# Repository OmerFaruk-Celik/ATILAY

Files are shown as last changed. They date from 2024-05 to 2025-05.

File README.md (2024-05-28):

# ATILAY: Bilgi Paylaşımıyla Güçleniyoruz!

👋 Teknofest İnsansız Su Altı Otonom yarışmasında ATILAY takımı olarak yola çıkarken hedefimiz sadece yarışmayı kazanmak değildi. Aynı zamanda yazılım alanındaki bilgi birikimimizi siz yeni başlayanlarla paylaşarak Türkiye'deki kaynak sorununa çözüm bulmaktı. 🇹🇷

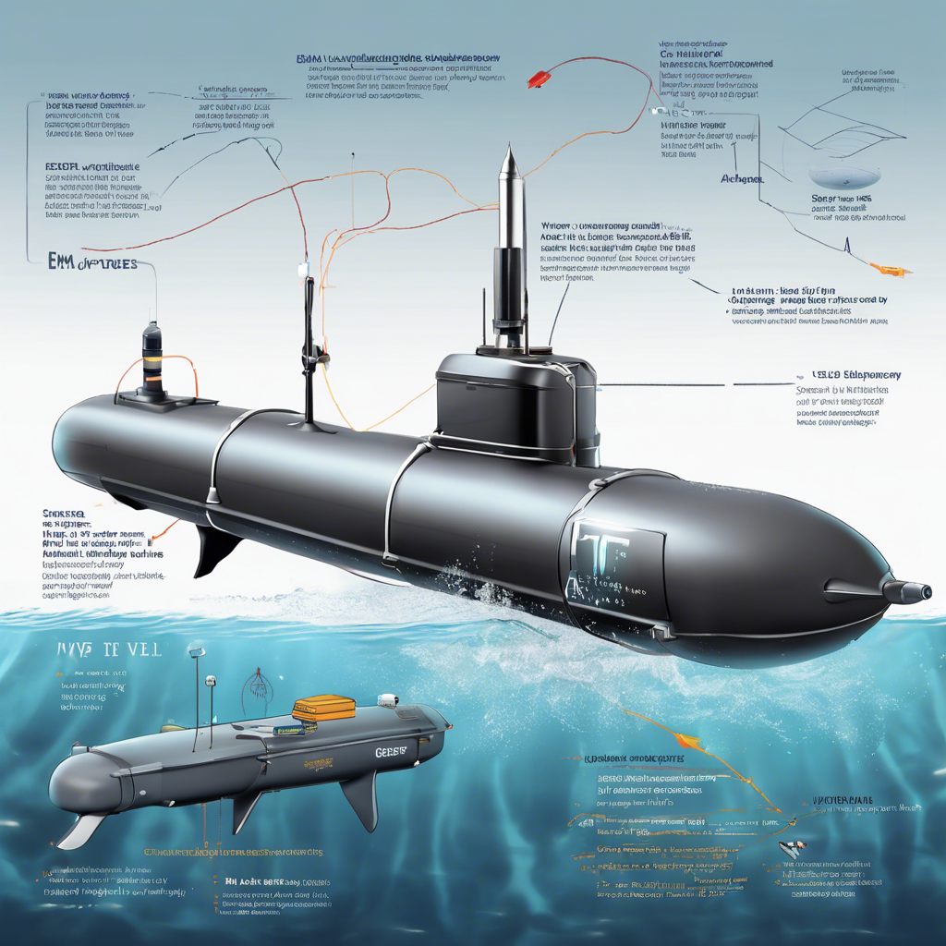
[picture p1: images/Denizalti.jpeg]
Denizaltı


Bildiğiniz gibi, özellikle Türkçe kaynak bulmak oldukça zor olabiliyor. ATILAY olarak biz de bu zorluğun farkındayız. İşte bu yüzden edindiğimiz tüm bilgi ve tecrübeleri sizlerle paylaşarak bu sorunu aşmanıza yardımcı olmak istiyoruz.

İnancımız, gerçek gücün bilgiyi paylaştıkça artacağı yönünde! Günümüzün yapay zeka çağında, iş birliği ve bilgiye erişim her zamankinden daha önemli. Açık kaynak kod felsefesini benimseyerek "Windowsça değil, Linuxça" davranmayı ve hep birlikte gelişmeyi hedefliyoruz. 🐧

GitHub hesabımızda sizlerle paylaşacağımız kaynaklar; tecrübelerimizden faydalanmanız, sorular sormanız ve hep birlikte daha güçlü bir yazılım topluluğu oluşturmanız için bir fırsat sunuyor! 💻

Unutmayın, bilgi paylaştıkça çoğalır! ✨

# ATILAY: 2024 TEKNOFEST İnsansız Su Altı Sistemleri Yarışması

## 🏆  ATILAY Takımı

**Bu proje, 2024 TEKNOFEST İnsansız Su Altı Sistemleri Yarışması'nda "İleri Kategori"de yarışmak için oluşturulan ATILAY Takımı tarafından gerçekleştirilmektedir.**

**Takımımız:**

* **[Takım Üyelerinin Adları ve Rolleri]** 
* **Danışman:** [Danışmanın Adı ve Ünvanı]

**Başvuru ID:** 1295858

## 🚀  Proje Hedefi: Sualtı Keşif ve Operasyonlarda Yenilikçi Çözümler

**ATILAY** olarak, ülkemizin deniz kaynaklarını daha iyi keşfetmek, denizaltı araştırmalarını geliştirmek ve acil durumlarda hızlı müdahaleyi sağlamak için **insansız su altı sistemleri teknolojisine** odaklanmış, yenilikçi bir proje geliştirdik. 

**Projemizin temel amacı, sualtı araçlarına, GPS sinyallerinin ulaşamadığı ortamlarda da güvenli ve etkili bir konumlandırma yeteneği kazandırmaktır.** Bu sayede, sualtı keşifleri ve operasyonları daha verimli, güvenli ve maliyet etkin hale gelecektir.

## ⚙️  ATILAY: Sualtı Araçları için Arttırılabilir Menzilli Konumlandırma Sistemi (AMKS)

**AMKS**, sualtında ses dalgalarını kullanarak, ikili sayılarla kodlanmış zaman bilgisi ile aracın konumunu belirleyen yenilikçi bir sistemdir.

**AMKS'nin temel özellikleri:**

* **Uzun Menzil:**  Sinyal güçlendirici sayesinde, AMKS geleneksel sistemlere göre daha uzun mesafelerde konum belirleme olanağı sağlar.
* **Taşınabilirlik:**  İstasyonlar, aracın boyutuna göre ölçeklendirilebilir ve istenilen konuma yerleştirilebilir.
* **Maliyet Etkinliği:**  AMKS, LBL, SBL ve USBL sistemlerine kıyasla daha düşük maliyetlidir.
* **Güvenlik:**  Aracın konumunu belirlemek için birden fazla istasyon ve iki yönlü ölçüm gerektirmez.
* **Gizlilik:**  AMKS, pasif sonar prensibiyle çalıştığı için aracın konumunu aktif olarak ifşa etmez.

## 🤖  Yazılım ve Algoritmalar

**AMKS'nin çekirdeğini, güçlü bir yazılım ve algoritma seti oluşturmaktadır:**

* **Raspberry Pi 4:**  Aracın beyni olarak görev yapar, sensör verilerini işler, algoritmaları çalıştırır ve kontrol sinyalleri üretir.
* **Google Coral Devletme Kartı:**  Görüntü işleme ve derin öğrenme uygulamaları için kullanılır.  
* **Python:** Ana programlama dili olarak seçilmiştir, zengin kütüphaneleri ve kolay kullanım imkanı sunar. 
* **OpenCV:** Görüntü işleme ve analiz için kullanılır (örneğin, hedef algılama, renk tespiti).
* **NumPy:** Nümerik hesaplamalar için kullanılır (örneğin, matris işlemleri).
* **Pandas:** Veri analizi ve manipülasyonu için kullanılır (örneğin, sensör verilerini işlemek).
* **Scikit-learn:** Makine öğrenmesi algoritmaları için kullanılır (örneğin, anomalileri tespit etmek).
* **Matplotlib:** Veri görselleştirme için kullanılır (örneğin, model performansını analiz etmek).

**Kullandığımız algoritmalar şunlardır:**

* **Arama ve Tarama Algoritması:** Araç, havuzun haritasını çıkararak hedefleri belirler ve tekrar taramaktan kaçınır.
* **Renk Tespiti ve Kapıdan Geçiş Algoritması:**  Aracın belirli renkleri tespit ederek, kapıdan geçmesini sağlar. 
* **Su Altı Kablo Takibi ve Anomali Tespiti Algoritması:**  Aracın su altı kablosunu takip etmesini ve üzerindeki anomalileri tespit etmesini sağlar.
* **Hedefe Torpido Fırlatma Algoritması:** Aracın hedefleri tespit etmesini ve torpidoları fırlatmasını sağlar.

## 📡  Sensörler

**AMKS'nin donanımını oluşturan sensörler:**

* **LIDAR-Lite v3HP:**  Yüksek hassasiyetli optik mesafe ölçüm sensörü (uzak mesafe ölçümü için).
* **TF03 (ToF) Lazer Mesafe Sensörü:**  Toz geçirmez, suya dayanıklı, 180m'ye kadar ölçüm yapabilen lazer sensörü (yakın mesafe ölçümü için).
* **Gravity BMX160+BMP388 10 DOF Sensör:**  İvmeölçer, jiroskop ve manyetometre  (aracın yönünü ve pozisyonunu belirlemek için).
* **Derinlik Basınç Sensörü:**  Aracın derinliğini ölçmek için kullanılır.
* **Ultrasonik Sensör:**  Aracın çevresindeki engelleri tespit etmek için kullanılır (yakın mesafe).
* **ELP 100 Derece Bozulma Yok HD Kamera Modülü:**  Sualtı görüntüleme için kullanılır (hedef tespiti, çevre analizi).
* **Sızıntı Sensörü:**  Su geçirmez haznede oluşabilecek sızıntıları tespit etmek için kullanılır.

## 🔌  Güç Yönetimi

**AMKS, enerji tasarrufu sağlayan bir güç yönetim sistemi kullanmaktadır:**

* **Markalonya 5000mAh 3.7 V 26650 Li-lon şarj edilebilir pil:**  Aracın enerji kaynağı.
* **3S 12.6V 4A Li-ion & Lipo Pil Şarj Devresi:**  Pilleri şarj etmek için kullanılır.
* **Elektronik Hız Sürücüsü (ESC):**  Motorların hızını ve yönünü kontrol eder.

## 🗺️  Proje Geliştirme Aşamaları

* **Sistem Tasarımı:**  AMKS'nin yapısal tasarımı, sensör seçimi, güç yönetimi, iletişim protokolleri gibi konuları kapsamaktadır.
* **Mekanik Tasarım:**  Aracın gövdesi, pervaneler, iticiler, su geçirmez hazne ve diğer mekanik parçalarının tasarımı ve üretimi.
* **Elektronik Tasarım:**  AMKS'nin elektronik bileşenlerinin seçimi, devre tasarımının yapılması ve prototipin oluşturulması.
* **Algoritma ve Yazılım Tasarımı:**  AMKS'nin otonom çalışmasını sağlayan algoritmaların geliştirilmesi, yazılım kodunun yazılması ve simülasyonlar.
* **Test ve Entegrasyon:**  Sistemin, laboratuvar ve havuz testlerinde denetlenmesi ve entegre edilmesi.

##  📸  Proje Görselleri

#Araç Tasarımı
AMKS Sistem Şeması
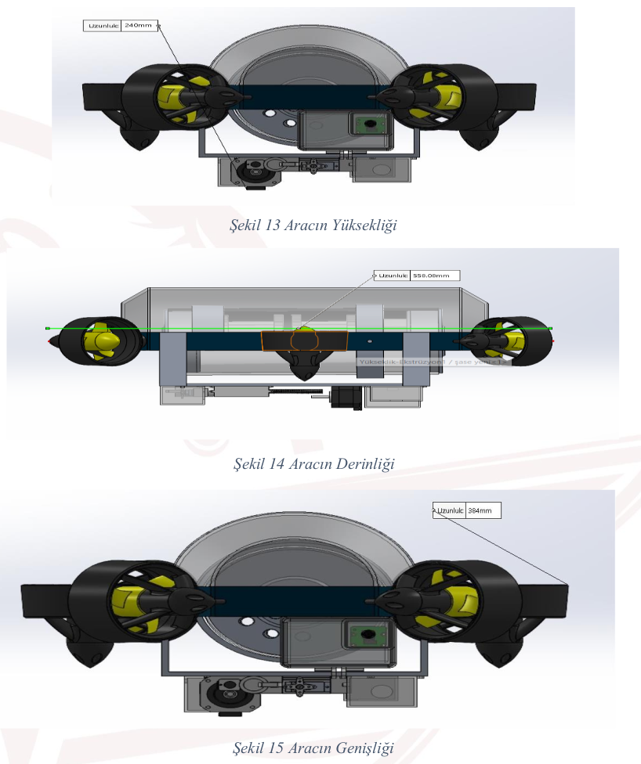
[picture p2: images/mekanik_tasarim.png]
Aracın Mekanik Tasarımı

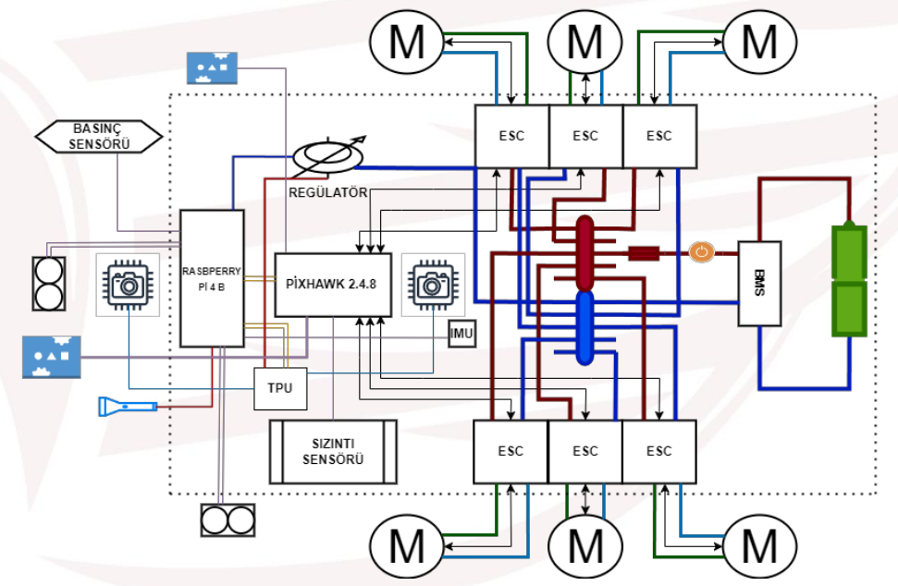
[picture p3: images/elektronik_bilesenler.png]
Elektronik Bileşenler


#Algoritmalar
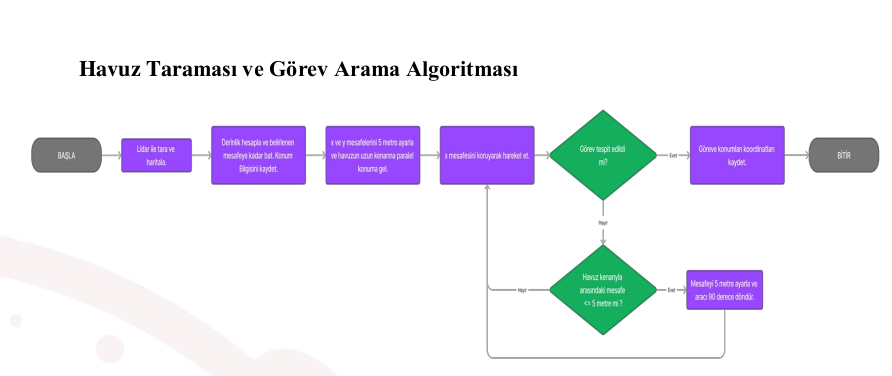
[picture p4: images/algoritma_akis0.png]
Algoritma Akış Diyagramı 1

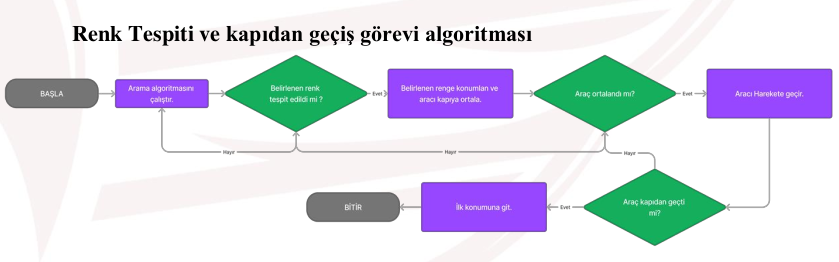
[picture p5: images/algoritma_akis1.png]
Algoritma Akış Diyagramı 2

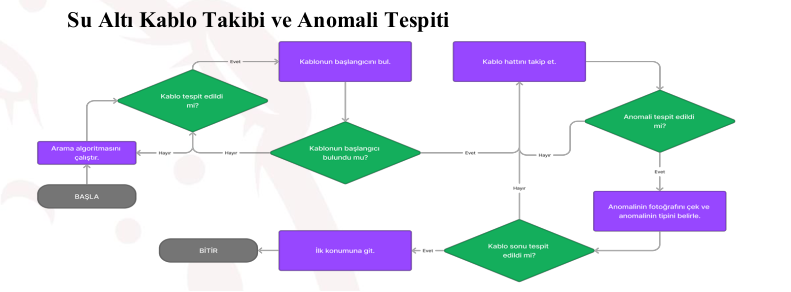
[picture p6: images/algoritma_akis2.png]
Algoritma Akış Diyagramı 3

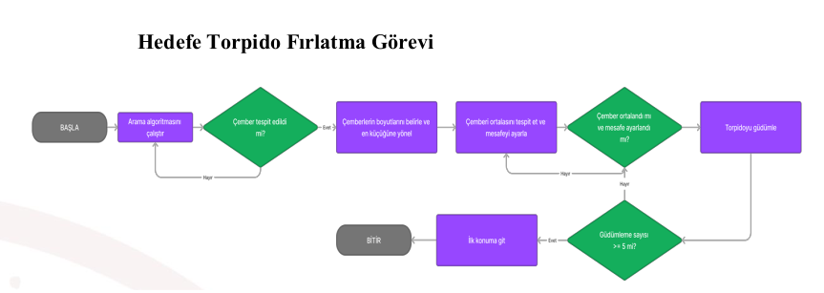
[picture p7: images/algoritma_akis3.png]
Algoritma Akış Diyagramı 4


#Didörtgen Tespiti
Dikdörgen Tespiti

#Simülasyonlar
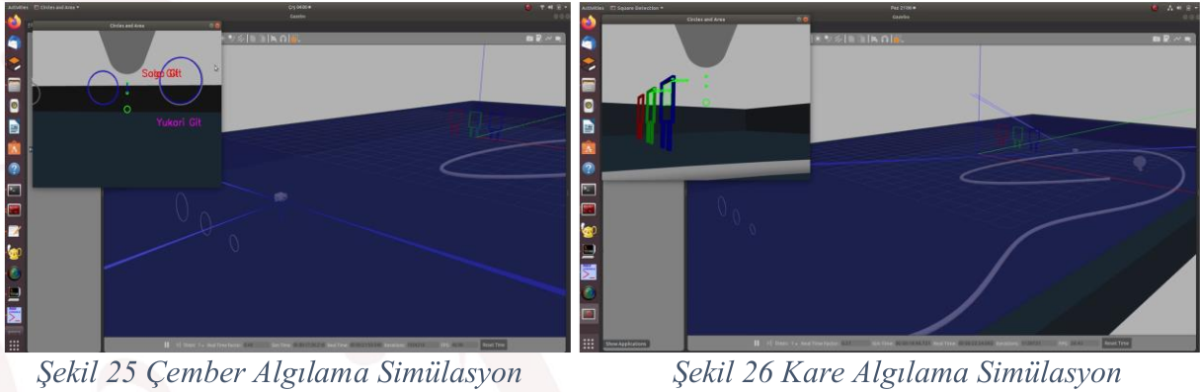
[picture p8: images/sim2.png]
Simülasyon Görüntüsü 1

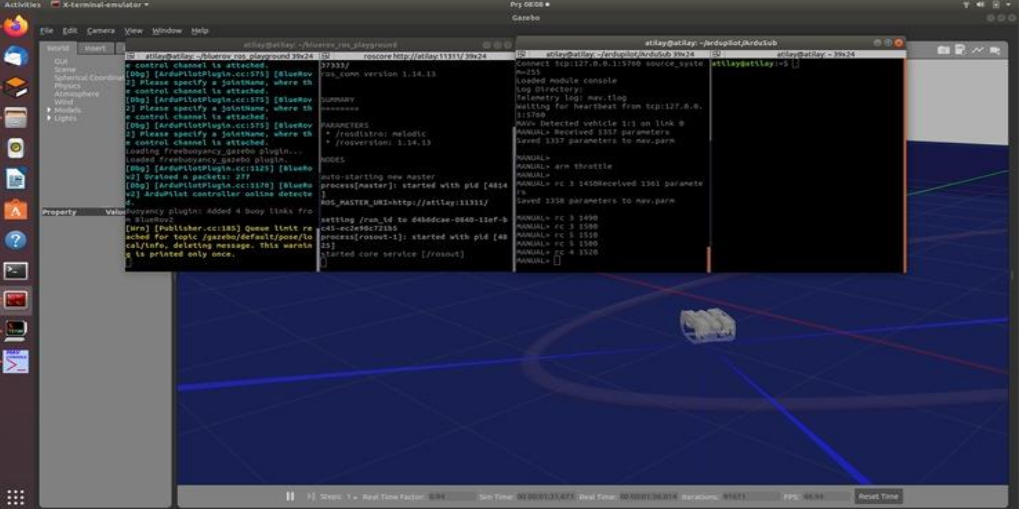
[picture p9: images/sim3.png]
Simülasyon Görüntüsü 2

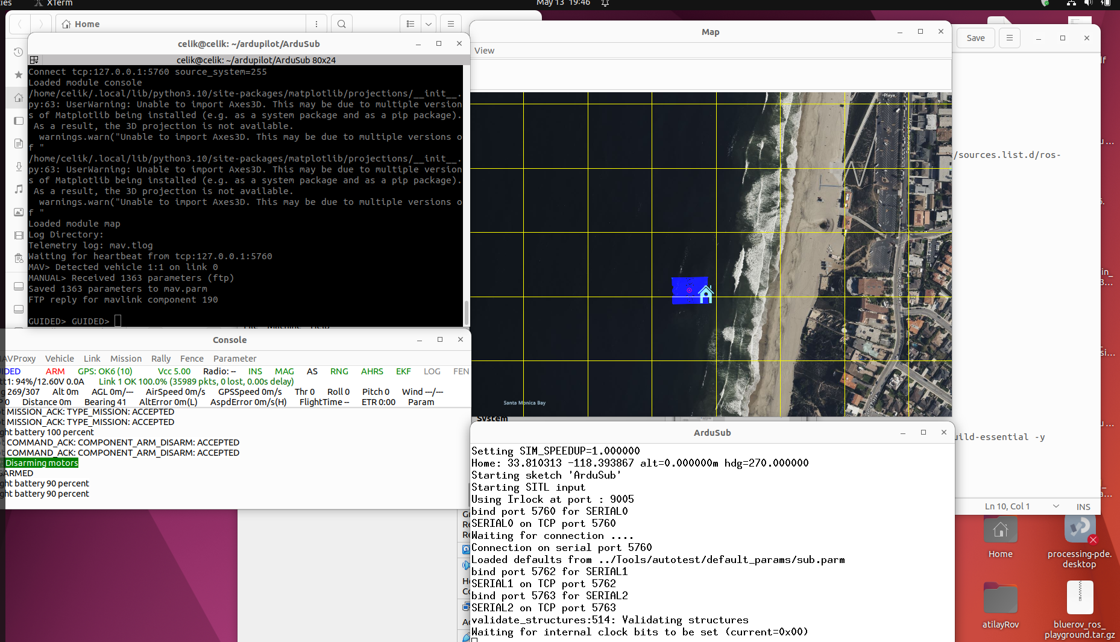
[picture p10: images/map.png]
Harita

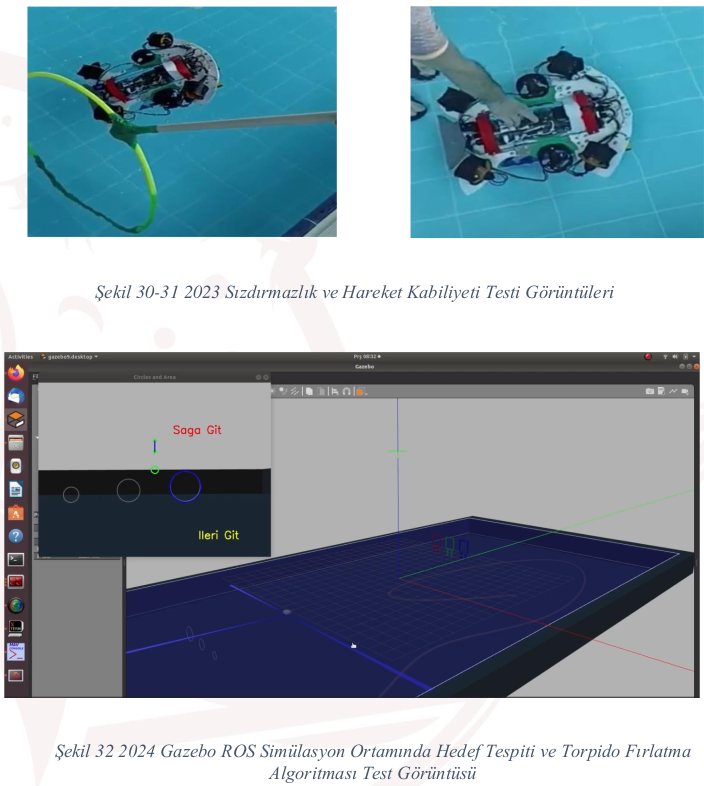
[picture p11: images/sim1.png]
Havuz Testi


#Kontrol İstasyonu
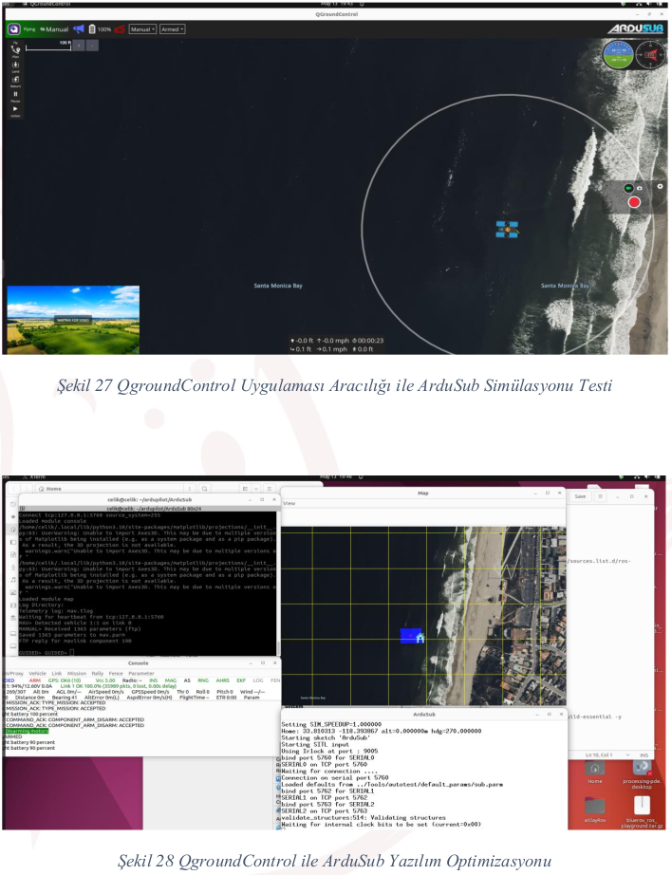
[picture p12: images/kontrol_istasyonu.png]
İstasyon


## 🤝  Katkıda Bulunma

ATILAY projesine katkıda bulunmak isterseniz, lütfen [GitHub repo linki](https://github.com/OmerFaruk-Celik/ATILAY) adresinden iletişime geçin.

## 📄  Lisans

Bu proje [Lisans Türü] lisansı altında yayınlanmıştır.

##  🎉  Teşekkür

Bu projeyi destekleyen TEKNOFEST'e ve projede çalışan tüm kişilere teşekkür ederiz. 

##  🌍  İletişim

* **[Takım E-posta Adresi]**
* **[Takım Web Sitesi Bağlantısı]**

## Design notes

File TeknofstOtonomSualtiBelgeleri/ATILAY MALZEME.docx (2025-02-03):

ATILAY MALZEME LİSTESİ

Ürün Adı | Ürün Açıklaması (Teknik Özellikleri) | Ürün Linki | Adet | Birim Fiyatı (TL) | Tutar (TL)
Tower Pro MG995 Yüksek Torklu Servo Motor - 360 Derece | Çalışma Voltajı: 4,8 ~ 7.2V/DC Taşıma Kapasitesi: 12KG Dönme Açısı: 360 Derece Rulman Tipi: Rulman Yok Dişli Tipi: Metal Dişli | Tower Pro MG995 Yüksek Hızlı Servo Motor - 12KG 360 Derece Satın Al | Robotistan (https://www.robotistan.com/mg995-yuksek-hizli-servo) | 2 | 178,5 | 357
TF03 (ToF) Lazer Mesafe Sensörü - LIDAR (180m) | Menzil – 180m@% 90 yansıtma, 70m @% 10 yansıtma Tespit edilmeyen bölge – 10cm Mesafe çözünürlüğü – 1cm Doğruluk - ± 10cm (10m'den az),% 1 (10m'den fazla) Tekrarlanabilirlik – 1σ ： <3cm | TF03 (ToF) Lazer Mesafe Sensörü - LIDAR (180m) Satın Al | Robotistan (https://www.robotistan.com/tfmini-plus-uzun-mesafe-lidar-modulu) | 1 | 11.338,71 | 11.338,71
LIDAR-Lite v3HP - Lidar Mesafe Sensörü | Menzil - 180m @% 90 yansıtma, 70m @% 10 yansıtma Tespit edilmeyen bölge - 10cm Mesafe çözünürlüğü - 1cm Doğruluk - ± 10cm (10m'den az),% 1 (10m'den fazla) Tekrarlanabilirlik – 1σ ： <3cm | LIDAR-Lite v3HP - Lidar Mesafe Sensörü Satın Al | Robotistan (https://www.robotistan.com/lidar-lite-v3hp) | 1 | 8465,56 | 8.465,56
Pixhawk 2.4.8 FC+Buzzer+ Safety Switch+I2C+SD Card+Neo-M8N GPS+GPS Holder+Power Module+PPM+RGB+Shock Absorber Board +DF13 4/5/6 Pin Cable | Paket İçeriği 1 Adet Pixhawk Otopilot 1 Adet M8N GPS 1 Adet GPS Tutucu 1 Adet Power Modül 1 Adet Titreşim Önleyici 1 Adet Safety Switch 1 Adet Buzzer Alıcı tipi 72 kanallı Ublox M8 motor GPS / QZSS L1C / A, GLONASS L10F, BeiDou B1 SBAS L1C / A: WAAS, EGNOS, MSAS Galileoya hazır E1B / C (NEO-M8N) Nav. güncelleme hızı1 Tek GNSS: 18 HZ'ye kadar Eş zamanlı GNSS: 10 Hz'e kadar. Konum doğruluğu 2,0 m CEP Duyarlılık İzleme ve Nav: –167 dBm. Soğuk çalıştırma: –148 dBm. Sıcak başlama: –156 dBm. Yardım AssistNow GNSS Çevrimiçi | Pixhawk 2.4.8 Uçuş Kontrol Kartı Seti (Combo Set) (dronmarket.com) (https://www.dronmarket.com/urun/pixhawk-2-4-8-fc-buzzer-safety-switch-i2c-sd-card-neo-m8n-gps-gps-holder-power-module-minim-osd-ppm-rgb-dual-ttl-3dr-433-915mh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) | 1 | 8467,73 | 8.467,73
Gravity: BMX160+BMP388 10 DOF Sensör | Çalışma Aralığı300-1250 hPa Çözünürlük0.3μT Jiroskop± 125 ° / s ~ 2000 ° / s Jeomanyetik Sensör± 1150uT (x-, y ekseni); ± 2500uT (z ekseni) | Gravity: BMX160+BMP388 10 DOF Sensör Uygun Fiyatıyla Satın Al - Direnc.net® (https://www.direnc.net/gravity-bmx160bmp388-10-dof-sensor) | 1 | 936,2 | 936,20
LentaMarine G-350 304 serisi | 12-25V Yüksek itiş ücüne sahip | https://lentamarine.netdunyasi.com.tr/g-350-insansiz-su-alti-araci-rov-iticisi-thruster | 6 | 3329,89 | 19.979,34
Molicel INR-18650-P28A - 3.7V 2800 mAh Li-ion Şarjlı Pil -35A | 3.7V 2800 mAh Li-ion şarj edilebilir pil | Molicel INR-18650-P28A - 3.7V 2800 mAh Li-ion Şarjlı Pil -35A Fiyatı, Yorumları - Trendyol (https://www.trendyol.com/molicel/inr-18650-p28a-3-7v-2800-mah-li-ion-sarjli-pil-35a-p-813041625?boutiqueId=61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) | 18 | 469,90 | 8.458,20
Sualtı Robot derinlik sensörü su derinliği basınç yüksek hassasiyetli düşük güç tüketimi MS5837 açık kaynak B30 | Su altı hassas basınç sensörü | Sualtı Robot derinlik sensörü su derinliği basınç yüksek hassasiyetli düşük güç tüketimi MS5837 açık kaynak B30 - AliExpress (https://tr.aliexpress.com/item/1005002564426304.html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) | 1 | 2910,48 | 2910,48
XHE20 2 Pin Su Geçirmez Konnektör Takım IP67 | Pin Sayısı2PinAnma Gerilimi500vAnma akımı30APanel Diş Çapı21 mm | XHE20 2 Pin Su Geçirmez Konnektör Takım IP67 Uygun Fiyatıyla Satın Al - Direnc.net® (https://www.direnc.net/xhe20-2-pin-su-gecirmez-konnektor-takim-ip67?language=tr&h=82807832) | 16 | 386,69 | 6187,04
XHE20 7 Pin Su Geçirmez Konnektör Takım IP67 | Pin Sayısı7 PinAnma Gerilimi500vAnma akımı15APanel Diş Çapı21 mm | XHE20 7 Pin Su Geçirmez Konnektör Takım IP67 Uygun Fiyatıyla Satın Al - Direnc.net® (https://www.direnc.net/xhe20-7-pin-su-gecirmez-konnektor-takim-ip67) | 6 | 386,69 | 2.320,14
8mm Rulman 608zz | 3d Yazıcı yada diğer uygulamalarında kullanılabilir mini rulman. Bilya kısımları iki taraftan koruyucu metal plaka ile kaplıdır. İç Çapı: 8mm Dış Çapı: 22mm En: 7mm | https://www.motorobit.com/8mm-rulman-608zz | 2 | 14,03 | 28,06
3D Yazıcı Z Ekseni Vidalı Mil Somun | 400mm - Trapez T8 8mm | https://www.robolinkmarket.com/3d-yazici-z-ekseni-vidali-mil-somun-400mm-trapez-t8-8mm-ender6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 | 1 | 186,60 | 186,60
Çelik Tornavida Seti 25 Parça | Profesyonel Tornavida Ucu Seti Telefon Bilgisayar Saat Tamir Hassas Tornavida | (amazon.com.tr) Çelik Tornavida Seti 25 Parça Profesyonel Tornavida Ucu Seti Telefon Bilgisayar Saat Tamir Hassas Tornavida | 1 | 349,99 | 349,99
Benz Tools Alyan anahtar seti | 31 parçalı iç altıgen set, kompakt çantada ek T sap dahil - her amaç için altıgen anahtar | (amazon.com.tr) Benz Tools Alyan anahtar seti - 31 parçalı iç altıgen set, kompakt çantada ek T sap dahil - her amaç için altıgen anahtar (alyan anahtar seti) | 1 | 474,51 | 474,51
Çelik İtme Yayı | DIŞ ÇAP:12.5mm İÇ ÇAP:9.5mm BOY:43mm TEL ÇAPI:1.5mm | https://www.n11.com/urun/yay-itme-celik-yay-5-adet-14759427 | 2 | 119,90 | 239,80
Çelik Sıkıştırma Yayı | tel çapı 0.15mm dış çapı 1mm uzunluk 3mm | https://tr.aliexpress.com/i/32832957410.html | 2 | 331,5 | 663
Sarf Malzeme | 3D Yazıcı flament Epoksi kaplama Bağlantı eleman ve ekipmanları Kablolar | | 1 | 15000 | 15000
| | | GENEL TOPLAM: | | 86362,36

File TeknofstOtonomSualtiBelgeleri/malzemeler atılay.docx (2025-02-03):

Odada bırakılanlar

Flamentler

Astar

Şırınga 1 tane

Sıvı conta

Boya fırçası 3 tane

Hızlı yapıştırcı

Perçin tabancası

Gres yağı

Bağ makası

Çift taraflı bant 1 tane

Zımpara

Hazne

3D parçalar

Yüzdürücü

Aldıklarımız

Monitor

Alet çantası 1 tane

Lehim makinası 1 tane, pompası 1 tane

Aurdino proje seti 1 tane

Motor hız sensörü 7tane

Fırçasız motor 8 tane

Su geçirmez soket

Regülatör (yükseltici) 4 tane

ESC 6 tane

Konnektör

USB kablo ve başlık 5 tane

Klemens 5 tane

Klavye

Servo 1 tane

Su geçirmez buton

Kumanda

Manyetik sensör

Buton (kuş buton) 2 tane

Konnektör

Soğutucu

Soket

Kamera haznesi 2 tane

Conta 5 tane

Zincir kilit 3 tane

Sıva altı sensör 1 tane

Slikon tabancası 1 tane

Etiketler 5 paket

Gözlük (koruyucu) 6 tane

İzolet bant 5 tane (3 tanesi küçük)

Conta-vida 1 kutu

Batarya şarj aleti 1 tane

Batarya şarj ünitesi

Penetratör 3 tane

SSD -----

vida seti 2 kutu

Regülatör voltaj yükseltici 3 tane

Flex kablo

Servo 1 tane

Direnç

Balans kablosu

Matkap ucu 1 kutu

Vernik ------

Sprey boya 3 tane

Hızlı yapıştırıcı ------

Silikon 2 tane

Silikon bant -------

Aracın kendisi

Uzatma

Kablolar 1 kutu

Makaron 1 poşet

Testere 2 tane

El aletleri 5 tane

Boya (akrilik) 4 tane

Eldiven çift halinde 3 tane, tekli 3 tane

Doğrama tahtası 1 tane

Strap

Termal macun -------

Emniyet pensi -------

Maske 12 tane

Sprey boya 3 tane

Çift taraflı bant 1 tane

3.7 ve 9 V piller 11 tane,10 tane 9v, 1.5v 3 tane ve 3 tane pil yatağı

Çubuk tahta 1 paket

Bulaşık teli 1 tane

Açılmamış reçine 1 tane

Lab gözlüğü 6 tane

Su terazisi 1 tane

Hortum 1 tane

Dijital kumpas 1 tane

Vida seti 2 kutu

Hassas terazi 1 tane

Bıçak sigorta 3 tane

Boya paleti 1 tane

Jelatin 2 tane

Uçuş kontrol kartı 1 tane

Kamera kablosu 3 tane

Lehim teli 1 tane

Motorun pervane bağlantı parçası (eksik parçaları var) 12 tane

Multimetre 1 tane

Clampmeter 1 tane

Tornavida seti 1 tane

Metre 1 tane

Gidon vida 20 tane

DIS play kablo 1 tane

joystick buton 1 tane

diyot 6 tane

coral 1 tane

şarj dengeleyici 1 tane

plastik kelepçe 1 paket

hafıza kartı 1 tane

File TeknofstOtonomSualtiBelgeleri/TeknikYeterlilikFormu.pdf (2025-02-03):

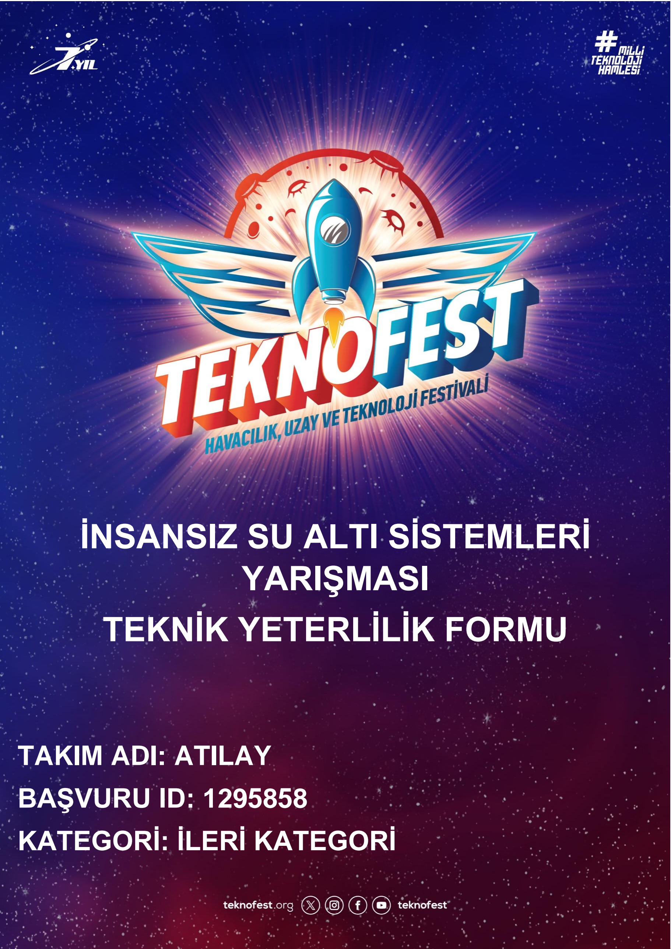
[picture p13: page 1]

# İNSANSIZ SU ALTI SİSTEMLERİ YARIŞMASI TEKNİK YETERLİLİK FORMU

# TAKIM ADI: ATILAY

# BAŞVURU ID: 1295858 KATEGORİ: İLERİ KATEGORİ

TAKIM TANITIMI

- ATILAY, 2021 yılında kurulmuş ve TEKNOFEST 2024’te de Su Altı Sistemleri Kategorisi’nde yarışacak bir OTONOM SİSTEMLER takımıdır. ATILAY Takımı’nın tüm üyeleri Fırat Üniversitesi’nden olmak üzere Havacılık Elektrik Elektroniği, Yazılım Mühendisliği, Bilgisayar Mühendisliği ve Mekatronik Mühendisliği öğrencileridir.

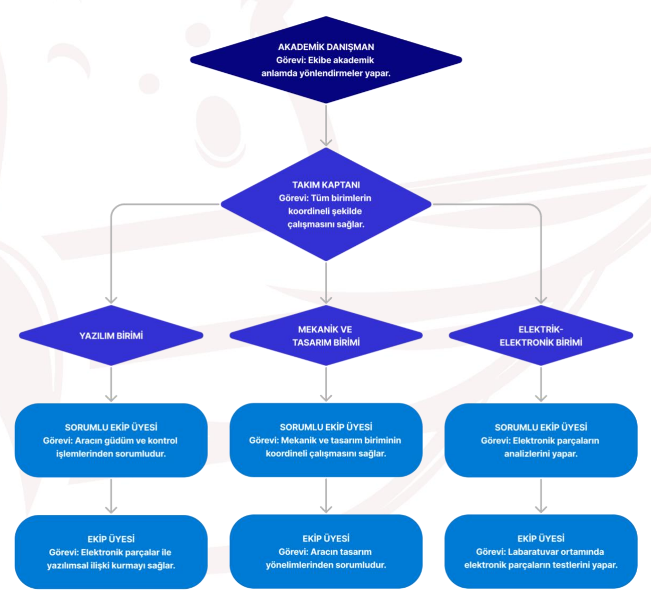
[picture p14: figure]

Şekil 1 - Takım Şeması

ARAÇ TASARIMI

- Ana gövde alüminyum, hazne kapakları demir, geri kalan parçalar ise PLA, ABS gibi malzemeler ile üretilecektir. Araçta hareket elemanları için motor ve servo kullanılacaktır. Aracın üretiminde CNC, 3D yazıcı, spiral, torna, vargel, kaynak ve yapıştırma yöntemleri ile vidalama kullanılacaktır. Kullanıma uygun hale getirilen sistem parçaları bir araya getirilerek elektronik ve yazılım sistemi ile uygun kulanım haline getirilecektir. Araç temelde 3 kısımdan oluşacaktır; sızdırmaz hazne, ana gövde, ana gövdeye bağlı hareket elemanları ve algılayıcılar. Bu üç kısımdaki elamalar ayrı ayrı üretilip montaja hazır hale geldiğinde bir araya getirilecektir. Üretim için sanayiden ve üniversitenin laboratuvarlarından yararlanılacaktır.

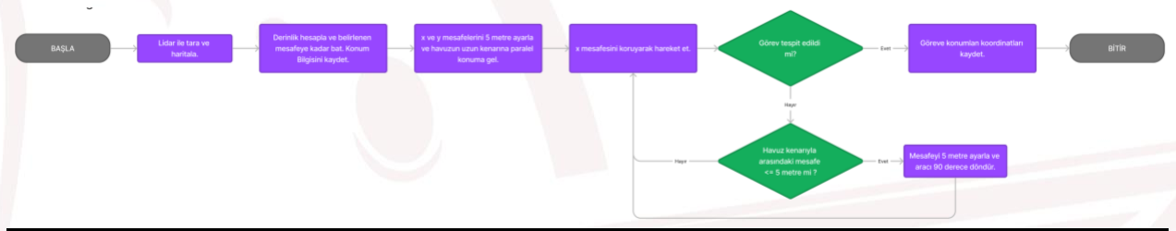
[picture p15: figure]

Şekil 2 - Arama Algoritması

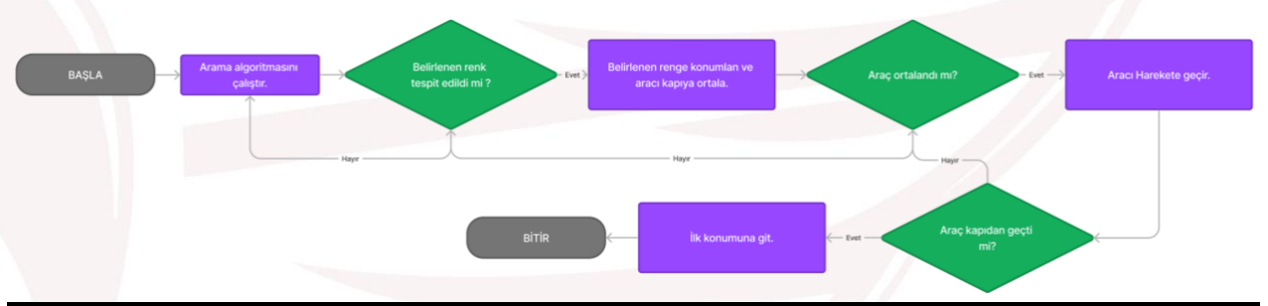
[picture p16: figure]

Şekil 3 - Renk Tespiti ve Kapıdan Geçiş

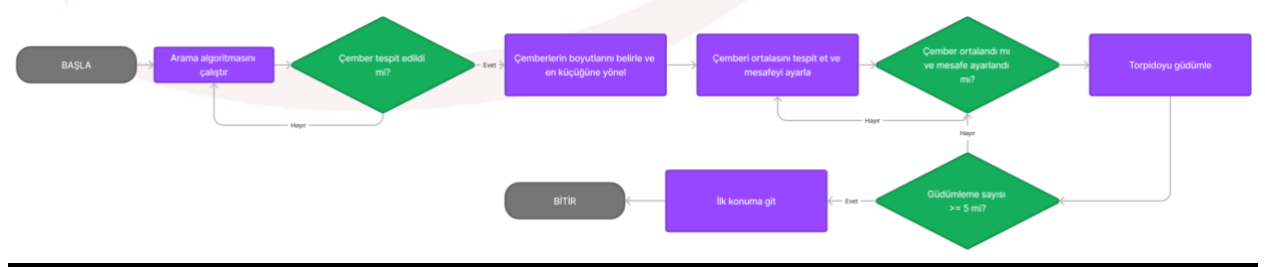
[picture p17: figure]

Şekil 4 - Otonom Torpido Fırlatma

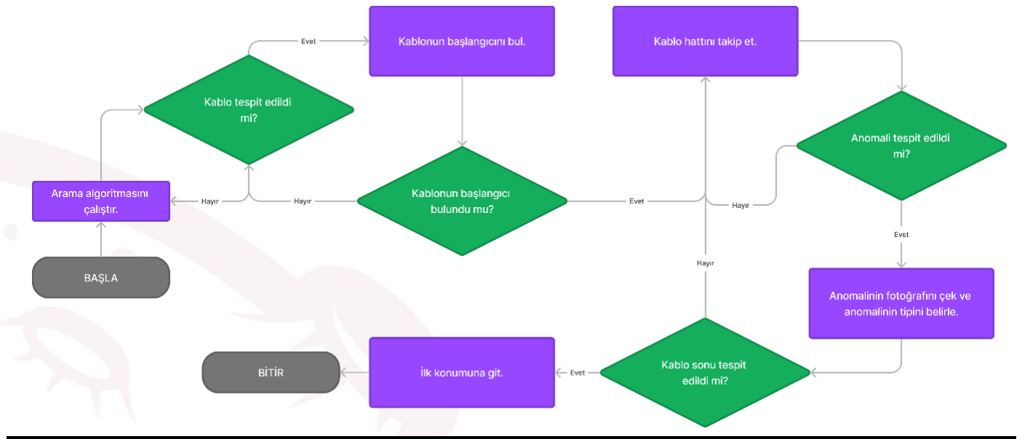
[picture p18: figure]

Şekil 5 - Su Altı Kablo Takibi ve Anomali Tespiti

BİLEŞENLER | ÜRETİCİ | MODEL | ÖZELLİKLERİ | FİYAT
| | MEKANİK
Yüzdürücü Kullanımı | LentaMarine | G-350- 304 serisi | İtki gücünden faydalanılarak yüzme işlemi yaptırılacaktır | 2.727 * 6 = 16.362 TL
Şase | | Alüminyu m | Dayanıklılık ve işlenmesinin kolay olası | Envanter
Sızdırmaz Hazne | | Pleksi | Saydam olması işlenmesinin kolay olması ve suya dayanıklılığı | Envanter
Sızdırmaz Konnektörler | direncnet | XHE204 | 30A anma akımına dayanaklı su geçirmez konnektör | 385,88 * 16 = 6.174,08

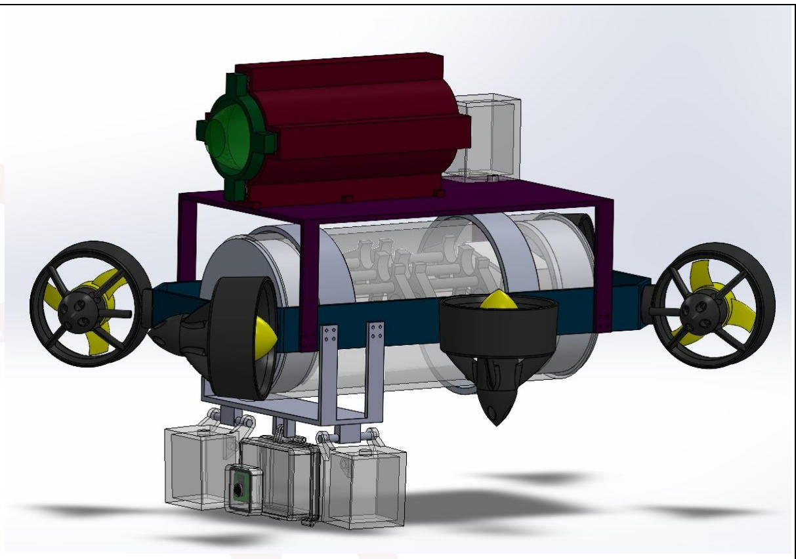
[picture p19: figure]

Şekil 6 - Planlanan Araç Tasarımı

BİLEŞENLER | ÜRETİCİ | MODEL | ÖZELLİKLERİ | FİYAT
| | İTKİ SİSTEMİ
İtici (Thruster) | LentaMarine | G-350 | 304 serisi paslanmaz çelik ile kullanım ömrü uzundur. Diğer motorlara kıyasla uzun ömürlü ve kullanışlıdır. Ayrıca 12-25V arası tüm değerlerde çalışır. | 2.727 * 6 = 16.362 TL
İtici Kontrolcüsü | LentaMarine | 30A ESC Çift Yönlü | Su altı iticileri yüksek hassasiyet ve verimli bir şekilde 30A değerine kadar rahatlıkla kontrol edebilir. | ENVANTER

Pervaneler LentaMarine

G-350
Motoru
Pervanesi

### 78 mm çapı ile G-

350 motoruna sabit
olan | bu | pervane,
motorun | teknik
özelliklerini
destekleyerek
yeterli | itkiyi
üretebilmektedir.

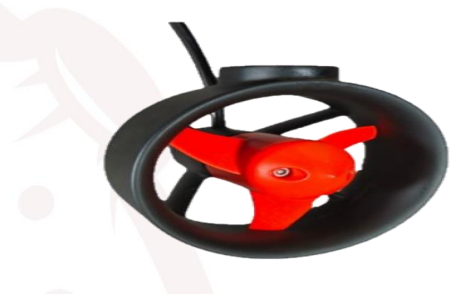
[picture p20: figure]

Şekil 7 – G-350 Motoru

BİLEŞENLER | ÜRETİCİ | MODEL | ÖZELLİKLERİ | FİYAT
| | ELEKTRONİK
İşlemci Kartları | Raspberry | Raspberry Pi 4 8GB | 4K ekran performansı, hızlı kod çözme yeteneği, hızlı CPU yeteneği bulunmaktadır. Ayrıca -50°C sıcaklık değerine kadar çalışabilmektedir. | ENVANTER
Otopilot Kartları | Pixhawk | PX4 PIX 2.4.8 32 Bit | Kullanılacak olan programlama dili Python ile uyumlu çalışmakta, kullanılacak olan sensörleri destekleyerek yazılım algoritmasının basitleştirilmesini sağlar. | ENVANTER

Batarya | Molicel | INR-18650-P26A | Kullanılacak olan pil modülü az maliyet ile uzun pil ömrü sağlayacaktır. | 300 * 18 = 5400 TL
Gerilim Çeviriciler | TECH PUBLIC | LM2596 dc-dc | Gelen gerilim seviyesini, istenilen gerilim seviyesine çevrilmesini sağlar. | ENVANTER
BİLEŞENLER | ÜRETİCİ | MODEL | ÖZELLİKLERİ | FİYAT
| | SENSÖRLER
Kamera Modülü | Raspberry | Raspberry Pi V2 | Araçta yer verilen görüntü işleme kartı ile uyumlu olan Raspberry kamera, yüksek hassasiyetli ve hızlıdır. Yüksek beyaz dengeleme özelliğine sahiptir. | ENVANTER
Sızıntı Sensörü | B1R TECH | BS-SBX-1M | Az miktarda da olsa sızıntı suyun konumunu algılayarak uyarı verir ve müdahale eder. | ENVANTER
Derinlik/Bası nç Sensörü | ROV | MS5837 | Yüksek hassasiyetli su derinliği ölçümü için ideal olan yeni nesil yüksek çözünürlüklü arabirim basınç sensörüdür. | 2007 TL
LiDAR | BENEWAKE | TF03 LiDAR | Lazer darbeleri kullanılarak bir yüzeyin üzerine düşen darbeleri tekrar toparlayarak mesafe ölçümü yapar(Ön Lidar). | 11.203,33 TL
LİDAR | Sparkfun | LiDAR Lite v3 HP | Haritalama ve engel tespiti (Yan Lidar). | 8.364,48 TL
Servo | Tower Pro | MG995 | Yayı gerer | 146,23 * 2 = 292,46 TL

IMU | Bosch
Sensortec

BMX160+B
MP388 10
DOF
Pusula | tayini | ve
aracın üç eksendeki
ivmesini ölçer.

934,24 TL

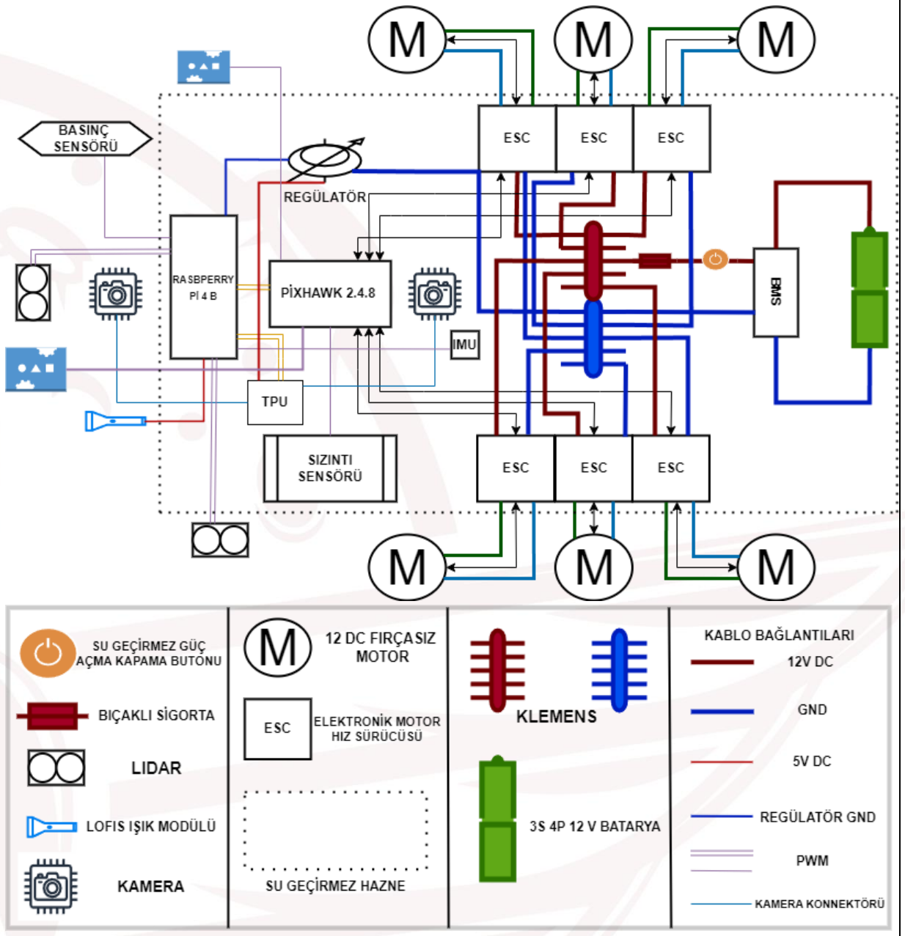
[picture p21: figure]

Şekil 8 - Elektronik Sistem Tasarımı ve Lejant

BİLEŞENLER | ÜRETİCİ | MODEL | ÖZELLİKLERİ | FİYAT
| | ALGORİTMALAR
Görüntü İşleme | Google | Tensoflow
| | 2.7
Yapay | sinir
ağları | ile | derin
örenme | için
| | | kullanılır | -

Akustik Sinyal İşleme | - | - | - | -
Navigasyon, Güdüm, Kontrol | Ardupilot | Ardusub | Pixhawk gibi otokontrol kartlarının kontrolünü sağlayan ve su altı araçlarında kullanılan kontrol yazılımıdır. | -

Açık Kaynak
Kodlu
Yazılımlar

Ros

Ubuntu

Gazebo

Mavlink
Protokolü

Python

Melodic

18.04

9

Pymawlin
k
.py

3.3+

Oluşturulan
simülasyon aracına
gerekli özellikleri
ekler. Simülasyonda
sensörler arasındaki
iletişimi sağlar.
Ros, | Gazebo,
Arduoilot | | vb.
Gerekli yazılımların
ortak çalışabildiği
Linux tabanlı işletim
sistemidir.

Simülasyon ortamı
sağlar.
Araçlar | ve | yer
istasyonları
arasında | veri | ve
komut | göndermek
için kullanılan seri
protokldür.
Proje | | ve
algoritmaları
geliştirmekte
kullanılan yüksek
seviyeli yazılım dili

GÖREV ÖZEL DONANIMLAR

Renk Tespiti ve Kapıdan Geçiş | Raspberry Pi V2 Kamera, TF03(ToF) Lidar,Lite v3HP Lidar, 6 adet G-350 su altı fırçasız motorlar.
Su Altı Kabloları Takibi ve Anomali Tespiti | Raspberry Pi V2 Kamera, 6 adet G-350 su altı fırçasız motorlar,TF03(ToF) Lidar, Lite v3HP Lidar.
IMU | Bosch Sensortec | BMX160+B MP388 10 DOF | Pusula tayini ve aracın üç eksendeki ivmesini ölçmede kullanılmasını sağlar. | -
Kamera Modülü | Raspberry | Raspberry Pi V2 | Hedef tespiti | -
Derinlik/Bası nç Sensörü | ROV | MS5837 | Aracın bulunduğu derinliğinin tespiti | -
LİDAR | Sparkfun | LiDAR Lite v3 HP | Haritalama ve engel tespiti (Yan Lidar) | -
LiDAR | BENEWAKE | TF03 (ToF) | Haritalama ve engel tespiti (Ön Lidar) | -
GPS | Pixhawk GPS Modülü | 2.4.8 | Aracın koordinat sisteminde yönünü bulmasını sağlar | -
Servo | Tower Pro | MG995 | Yayı gerer | -
Helezon Yay | 100 N’luk yay | Sanayi | Torpidoyu fırlatmak için gerekli enerjiyi depolar | -
Torpido haznesi | 3D Yazıcı | -- | Torpidoların muhafaza edildiği bölme | -
Form İçerisinde Yer Alan Fiyatların Toplamı | | | | 50.737,59 TL

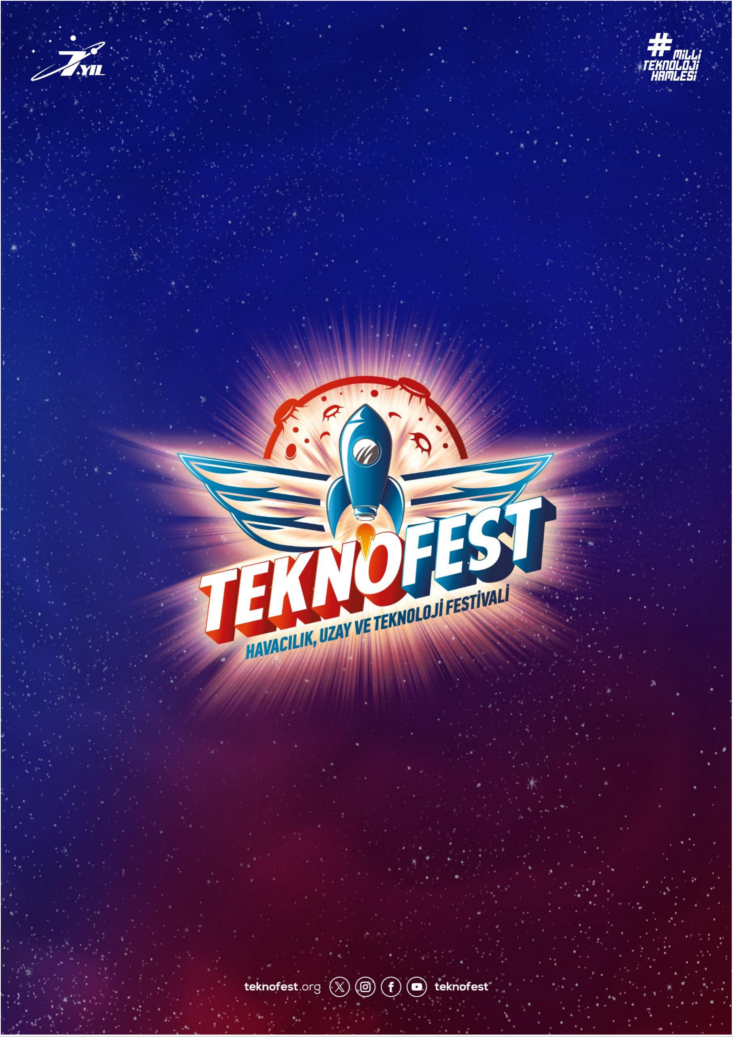
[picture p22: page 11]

### 1 İLERİ KATEGORİ

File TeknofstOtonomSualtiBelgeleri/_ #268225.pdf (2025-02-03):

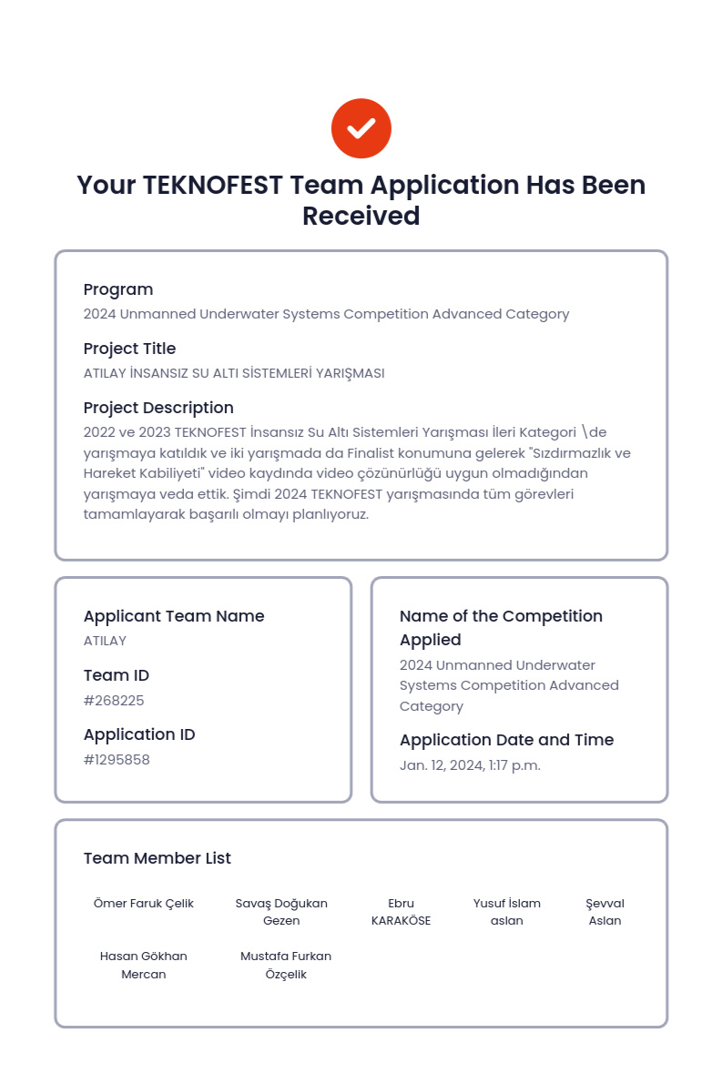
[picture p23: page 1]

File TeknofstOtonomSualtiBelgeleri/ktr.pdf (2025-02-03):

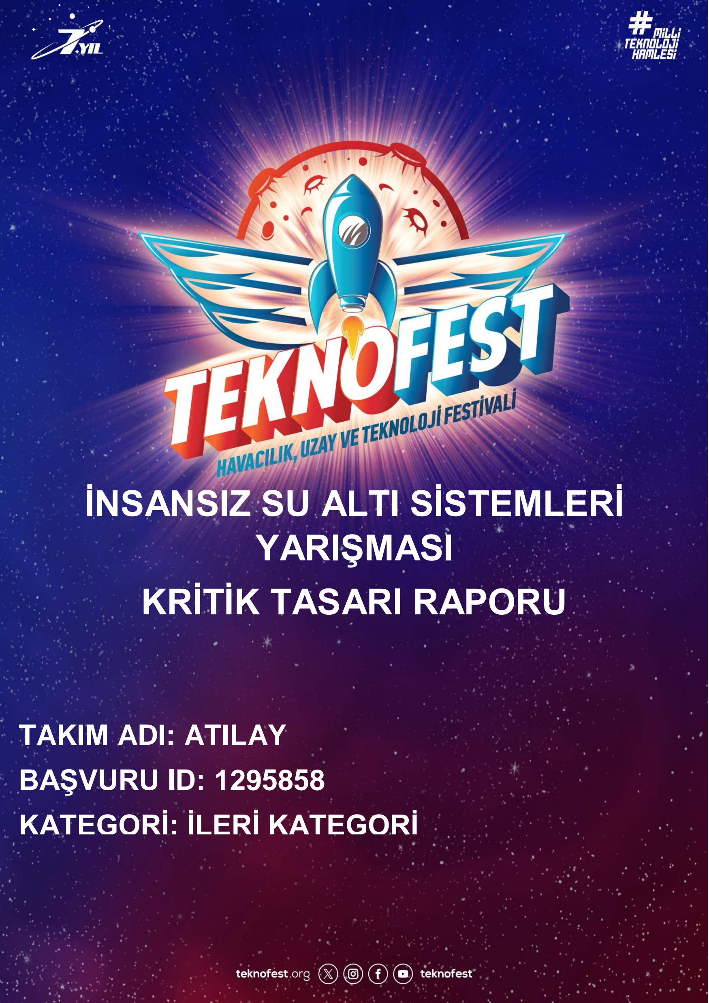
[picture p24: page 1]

1

# İNSANSIZ SU ALTI SİSTEMLERİ YARIŞMASI KRİTİK TASARI RAPORU

# TAKIM ADI: ATILAY

# BAŞVURU ID: 1295858 KATEGORİ: İLERİ KATEGORİ

2

İÇİNDEKİLER

3

### 1. RAPOR ÖZETİ

Tüm bu hedefler doğrultusunda kurulan ATILAY Takımı olarak 2024 TEKNOFEST İnsansız Su

Altı Sistemleri Yarışması için meydana getirilecek aracı geliştirerek insansız su altı sistemleri

teknolojisinde, üç tarafı denizlerle çevrili ülkemize hizmet etmeyi amaçlamaktayız.

ATILAY Takımı olarak 2024 TEKNOFEST İnsansız Su Altı Sistemleri Yarışması KTR aşaması

için yazmış olduğumuz bu rapor; akademik rapor standartlarına uygun ve şartnamede belirtilen

hususlara dikkat edilerek oluşturulmuştur. Oluşturulan bu rapor kapsamında sunulan bilgiler aşağıdaki

gibidir:

1) ATILAY Takımı’nda yer alan danışman ile ekip üyelerinin görevleri, organizasyon şemasıyla birlikte detaylıca gösterilmiştir.
2) Oluşturulacak araca ait sistem tasarımı, TYF’de sunmuş olduğumuz tasarımdan farklı olarak kullanılan sensörler ve ara elemanlar daha detaylı şekilde açıklanarak güncellenip KTR raporuna eklenmiştir.
3) Araç için ÖTR raporumuzda yer alan tasarımımızdan büyük oranda vazgeçerek daha iyi aerodinamik yapıya sahip ve kolay montaj edilebilir yeni bir tasarım gerçekleştirdik. Yeni geliştirdiğimiz final tasarımı ve final tasarımı ait olan; ana şase, iticiler, su geçirmez hazne, iticilerin ek parçaları, motor dikey bağlantı elemanları, motor muhafazası detaylı şekilde açıklanmıştır. Ayrıca araca ait akış analizi ile kabuk yapısı akış analizi yapılmış ve fiziksel özellikleri görsellerle birlikte açıklanmıştır.
4) Araçta kullandığımız malzemeler ile araç üretiminde kullanılan yöntemler, görsellerle desteklenmiş ve açıklanmıştır.
5) Elektronik tasarım sürecinde araç içinde kullandığımız sensörlerin neden seçildiği ayrıntılı şekilde yazılmıştır.
6) Araç için güç yönetimi ve dağıtımı, formüllerle desteklenerek açıklanmıştır.
7) Oluşturduğumuz algoritma şemaları, detaylı şekilde açıklanmış, kullanılacak elektronik ekipmanlarla ve görevlerle ilişkilerin nasıl yapılacağından bahsedilmiştir.
8) Yazılım tasarım süreci için kullandığımız diller ve neden seçildikleri açıklanmıştır.
9) Ara yüz tasarımı, su altındaki görüntünün iyileştirilmesi; görüntü, renk, şekil işleme işlemleri açıklanmış, ayrıca kontrastı arttırma, renk filtreleme işlemlerimiz; örnek kod çıktıları ve görsellerle birlikte desteklenerek rapora eklenmiştir.
10) Araç için laboratuvar ortamında gerçekleştirilen parçaların üretimi yapılırken güvenlik önlemleri alınmıştır. Alınan güvenlik önlemleri, maddeler halinde rapora eklenmiştir.
11) Oluşturulan algoritma şemaları, bilgisayar ortamında oluşturulan testlerle kontrol edilmiş ve test sonuçları görsellerle beraber açıklanmıştır. Ayrıca aracın sızdırmazlık ve hareket kabiliyeti testleri olimpik havuz ortamında yapılmıştır.
12) Zaman, bütçe ve risk planlamalarımız, detaylı şekilde tablolar halinde raporumuzda yer almıştır.
13) Yerlilik, özgünlük, referanslar ayrıntılı şekilde açıklanmıştır.

4

### 2. TAKIM ŞEMASI

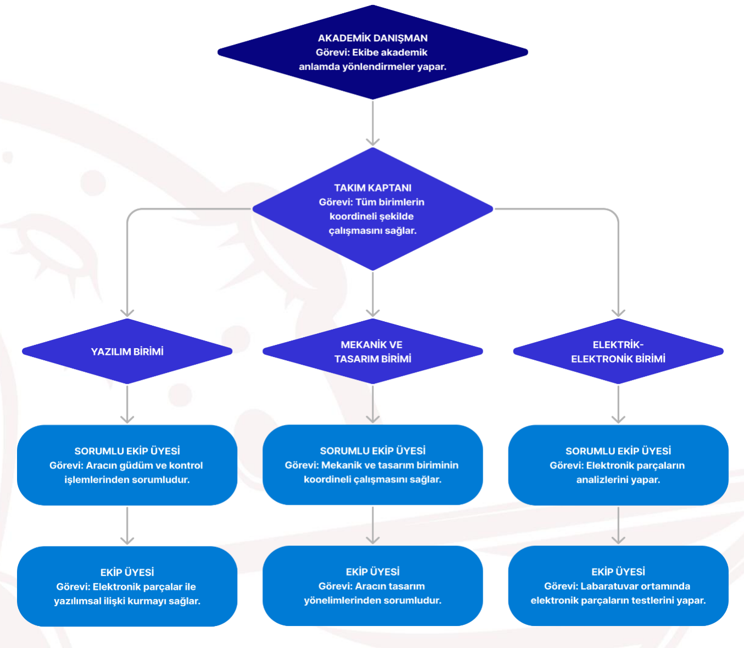
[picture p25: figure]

Şekil 1-Takım Görev Dağılımı

### 3. PROJE MEVCUT DURUM DEĞERLENDİRMESİ

ATILAY Takımı olarak 2022-2023 Teknofest İnsansız Su Altı Sistemleri Yarışmalarında ÖTR ve

KTR aşamalarını başarılı olarak geçmemize rağmen; Sızdırmazlık, Hareket Kabiliyeti ve Görev

Gösterimi Videosu aşamasında, 2022 yarışmasında aracımız suya batış sağlayamadığı için, 2023 yılında

ise video açısı hatalı olduğu içim finallere katılamadık. Takımımız bu sonucun ardından hız kesmeden çalışmalarına devam ederek tüm eksiklikleri giderip 2024 Teknofest İnsansız Su Altı Sistemleri

Yarışması’na katılma kararı almıştır. Bu sonuçla birlikte bir sonraki aşama olan KTR ’ye geçmeden

önce geçen yılki eksikliklerimizi, ekipçe uzun görüşmeler sonucunda belirledik. Hatalarımızı göz

önünde bulundurarak 2024 KTR aşamasına kadar yaptığımız değişiklikler aşağıdaki gibidir:

5

1) Aracımızın Sızdırmazlık, Hareket Kabiliyeti ve Görev Gösterimi Videosunda batmamasının sonuçları araştırılmış; ardından hazne içindeki hava vakumlanmış, 3 boyutlu parçaların basımları yenilenerek aracın batırılması sağlanmıştır.
2) Markalonya 5000 mAh 3.7 V 26650 Li-Ion Şarj Edilebilir Pil kullanımına karar verilerek daha az maliyetle daha çok enerji yoğunluğu elde edilmiştir.
3) Sistem tasarımımız, kullanacağımız sensörler ve ara elemanlar daha detaylı şekilde açıklanarak güncellenmiştir.
4) Araç tasarımımız, yaptığımız testler sonucunda, kolay montaj edilebilir ve daha aerodinamik yapıya kavuşabilir şekilde değiştirilmiştir.
5) Araç tasarımımız, elverişsiz yalpalama ve yunuslama hareketlerine yol açan yağmur ve türbülanslı rüzgârlar ve su altı aracını çevreleyen küçük dalgalar ile ideal olmayan koşullara uygun olarak yeniden tasarlanmıştır.
6) Aracımıza zemin tarama kamerası eklenmiştir.
7) Lidarların sayısı arttırılarak konum belirleme işlemlerinde bize yardımcı olacak verilerin desteklenmesi sağlanmıştır.
8) Yazılımda kullanılan algoritma ve kütüphaneler gözden geçirilmiş gerekli olan yerlerde değişikler yapılmıştır.
9) Kuyruk yapısı eklenerek hareket kabiliyeti arttırılmıştır.
10) Ön görüş kamerasının çözünürlüğü arttırılmış bu sayede görüntü işleme algoritmaları daha sağlıklı çalışması sağlanmıştır.
11) Basınç sensörünün konumu değiştirilerek aktif basınçtan etkilenmeyecek şekilde muhafaza edilmesi sağlanmış bu sayede pasif basınç ile verimli bir şekilde derinlik tespiti sağlanmıştır.

### 4. ARAÇ TASARIMI

4.1.Sistem Tasarımı

Önceki yarışmalar ve yaptığımız simülasyonların çıkarımları ile nihai sistem tasarımı TYF’de

de | belirtildiği | üzere | Şekil | 2’de | gösterildiği | gibidir.

6

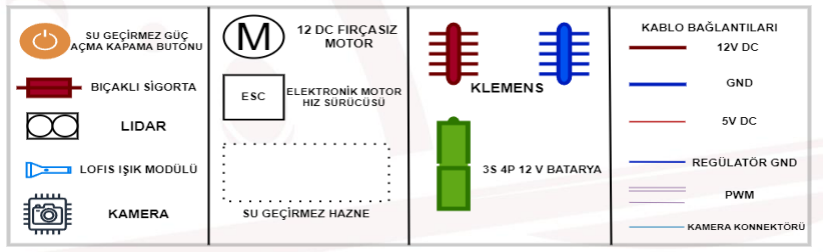
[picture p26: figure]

Şekil 2-Nihai Sistem Tasarımı

4.2.Aracın Mekanik Tasarımı

### 4.1.1. Mekanik Tasarım Süreci

Sualtı aracımızın mekanik tasarımı, birim ekip üyelerimizin yaptığı AR-GE çalışmaları

ve analizler sonucunda yeni şeklini almıştır. Ana amaç olarak kısıtlı süre içerisinde görevleri

yerine getirmek için tam performanslı bir araç tasarımı yapmak için çalışmalar yürütülmüştür.

Enerji tüketimini azaltmak, su içerisinde yeterli hız değerine ulaşmak için çeşitli kabuk

geometrisi ve pervane profillerinin analizlerini gerçekleştirdik. Tasarım sürecinde, aracın en-

boy-ağırlık ve havuz alanını göz önüne alarak aracımız için en uygun profili oluşturmayı

amaçladık. Bunların yanı sıra, üretim sırasında sualtı aracımızın estetik ve üretilebilir olmasını

göz önüne alarak, bu yönde bir tasarım oluşturduk. Aracımızı üretirken dikkat edilmesi gereken

mekanik özellikleri göz önüne alarak parçalarımızda kullanılan malzeme türleri fiyat

performans oranına dikkat ederek gereksiz maliyetten kaçınıldı uygun değerleri sağlayan

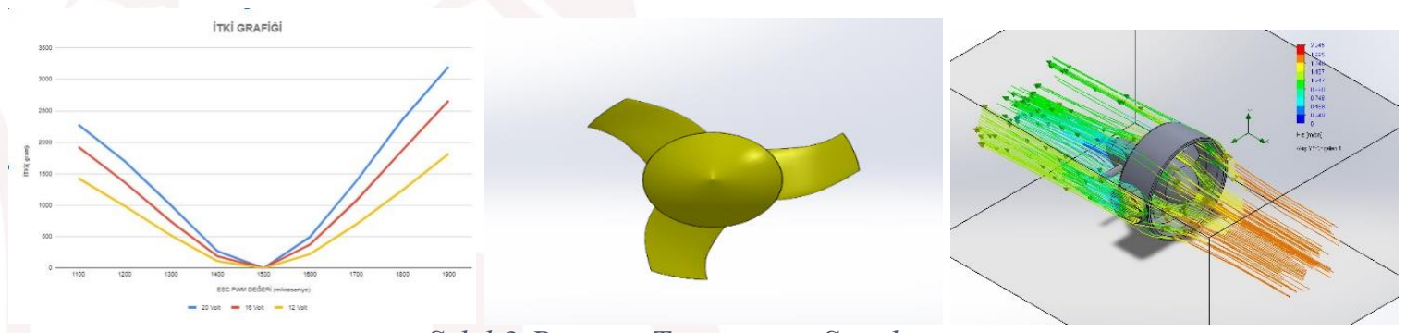
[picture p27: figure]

7

malzemeler üzerinde analizler yapıldı performans analizi ile fiyat analizi doğru orantılı olarak ölçülüp en iyi ürünler seçildi. Aracın analizleri yapılırken SOLİDWORKS ve FUSİON360

programları kullanıldı bağlantı elemanları seçilirken SOLİDWORKS ün toolboxın’dan

yararlanıldı. Araç tasarımı ilk adımda eskizler üzerinden yapılıp sonrasında takımın üyelerince değerlendirmeye tabi tutuldu. Üretilmesi kolay bir araç tasarımı tercih edildi gereksiz ağırlıktan

kaçınıldı aracın batmasını ya da su yüzeyinde kalmasını engellemek amaçlandı. Araç

tasarımının kolay seçilmesinin en temel sebebi ise kısıtlı süre içerisinde aracın final

yarışmasından önce testlere hazır hale getirip gerekli tam kapsamlı koşul ortamında da

değerlendirmeye alıp eksikliklerin giderilmesidir.

Pervane Tasarımı

Şekil 3-Pervane Tasarımı ve Simülasyonu

Pervane profilinin, yüksek itiş gücü, düşük sürtünme kuvveti sağlanması amaçlanmış, bu amaçla doğrultusunda sayısal testlere tabi tutuldu gerekli revizyonlar yapıldı ve gerekli itki gücünü oluşturana bir pervane profiline sahip olundu.

Ana Şase

Aracımızın ana şasesi, alüminyum plakanın CNC makinesinde tasarımımız

doğrultusunda kesilmesi ve gerekli kaynak işlemlerinin uygulanmasından sonra üretilmiş

olacaktır. Alüminyum plaka seçilmesinin temel nedeni hafif ve dayanıklı olmasıdır. Profilin

analizleri yapıldı ve istenen değerlerin 4 katına yakın değerlerde kuvvet uygulandı ve uygulanan

kuvvette de 2.31 katlık dayanım göstermiştir.

Şekil 4-Ana Şase

8

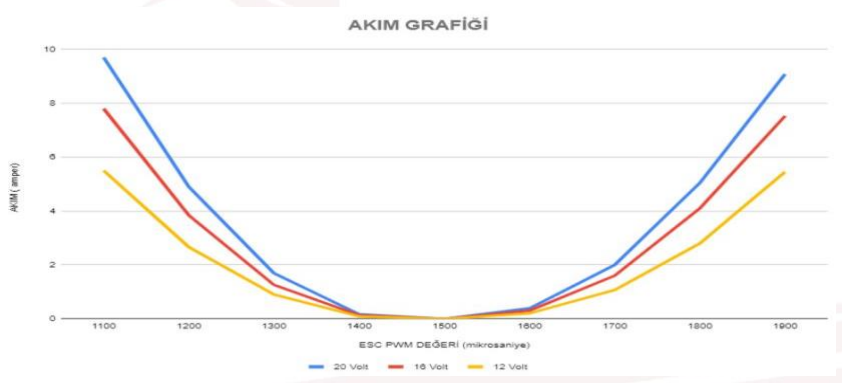
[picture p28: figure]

Şekil 6-Sızdırmaz Hazne Tasarımı

İticiler

Sualtı aracımızın motor seçiminde yeterli itkiyi sağlamak için RPM, tork ve enerji

tüketim oranı dikkate alınmıştır. Hem itki hem de denge için 6 adet ROV Su Altı motoru

kullanılmasına karar verilmiştir. 6 motordan 4 tanesi yatay eksende olmak üzere, 2 tanesi aracın

önüne, 2 tanesi aracın arkasına gelecek şekilde 45 derece konumlandırılacak böylece hem aracın

itki sistemine katkı sağlayacak hem de aracın dönüş (yaw) hareketini sağlayacaktır. Kalan 2

motor, aracın orta kısmında, aracın dikey ekseni yönünde suya batma ve çıkma hareketini

sağlayacaktır. Kullanılacak olan motorlar hem sızdırmazlık sağlaması hem de ortam koşullarına

daha dayanıklı olması nedeni ile Su Altı ROV motorları tercih edilmiştir. ROV motorlarının bir

diğer tercih edilmesin sebebi su altı güvenlik koşularını sağlamaktır.

Şekil 5-Akım Simülasyon Grafisi

Su Geçirmez Hazne Tasarımı

Aracımızda mekanik ekibi tarafından elektronik donanımları içine yerleştirileceğimiz,

bu malzemeleri sudan izole eden tüp şeklindeki bir yapı tasarlanmıştır. Bu yapı; akrilik tüp

(pleksiglas), flanşlar; O-halkalar, arka kapak ve konektörlerden(rakor) oluşmaktadır.

Kullandığımız flanşlardan iletişim ve güç için kullandığımız kablolar geçecektir kablo

geçişlerinde sızdırmaz konektörler kullanılacaktır.

9

Motor Şase Bağlantı Elemanı

Tercih etiğimiz motorun ana şase ile bağlantısını sağlayan yapımız bulunmaktadır

bağlantı elemanı olarak vida, somun ve pul kullanılacaktır. Gerek görülmesi durumunda sıvı

yapıştırıcılarda (silikon, reçine vb.) kullanılabilecektir.

Su Geçirmez Hazne Statik Analizi

Su geçirmez haznemize yaptığımız statik analizimizde, 2,5 metre havuz derinliği göz

önüne alınarak 0,12 MPa basınç uyguladık. Tanımladığımız malzemenin akma mukavemeti,

4,5e+07 N/m^2, haznemizin maruz kaldığı maksimum stres değeri ise 1,359e+07 N/m^2. Bu

hesaplamalara göre haznemizin 2 metre derinlikteki havuz koşulunda 21 kat güvenlikli olduğu

ve 200 metre basınç derinliğine kadar su basıncına dayandığı gözlemlenmiştir.

Kabuk Yapısı

Aracımızın kabuk tasarımı yapılırken bu bölgelerin sıvılarla temas eden en önemli bölgeler olduğu göz önüne alınarak yüksek performanslı hidrodinamik yapı oluşturmak amaçlanmıştır. Gerekli testler yapılarak kabuk tasarımı revize edilmiştir maliyeti düşürmek amaçlanmıştır. Kabukta oluşan maksimum yer değiştirme 0.044 mm kadar gerekli değerleri göstermiştir.

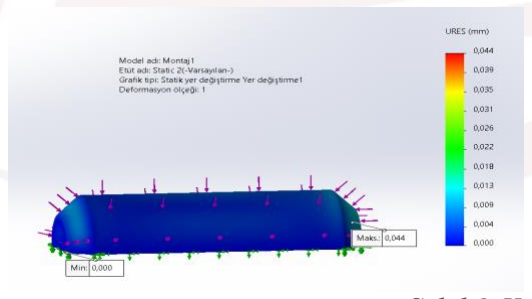
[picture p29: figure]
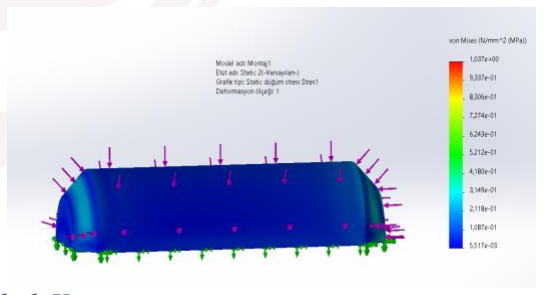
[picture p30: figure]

Şekil 8-Kabuk Yapısı

Şekil 7-Su Geçirmez Hazne Tasarım ve Simülasyonu

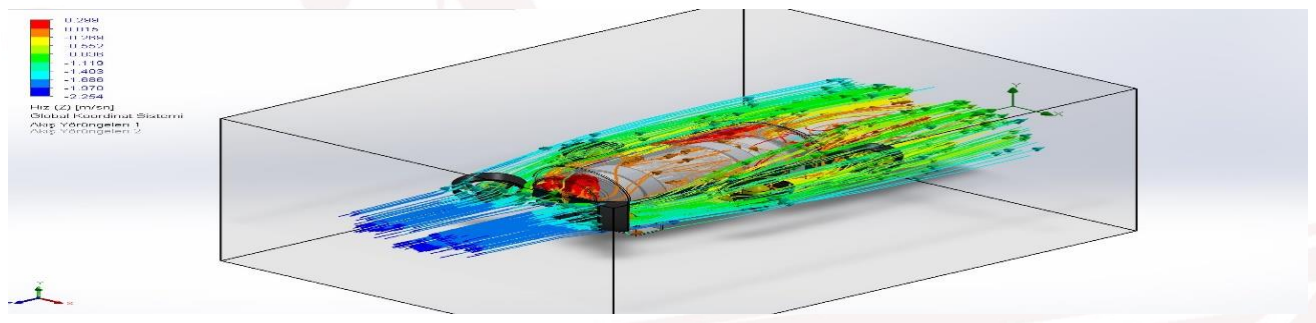
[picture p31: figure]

10

Sınır koşulları;

Hesaplama alanı için basınç, su yoğunluğu ve su sıcaklığı sırasıyla 101325 Pa, 999.79

kg/ms ve 273.16 K olarak kabul edilmiştir. Başlangıç giriş sınır koşulu, sabit hızda (2 m/s) dayalı

olarak, motor RPM değerimiz ise kullandığımız G350 ROV 12V DC 350KV değerinde su

geçirmez fırçasız motorun maksimum değerleri ele alınmıştır.

Araç Akış Analizi

Kabuk ve pervane yapılarına yapılan analizler sonucunda aracımızın nihai tasarımına

ulaşıldı. Nihai tasarım üzerinde yapılan akış analizinde, kabuk yapımızda elde ettiğimiz verilere

yakın değerlerde sonuçlar gözlemlendi. Başlangıç giriş sınır koşulu sabit hızda 2m/s dayalı

olarak kabul edilmiş, bu değerin pervane itkisi hesaplamalara katılmayarak, kabuk ön-üst

yüzeyinde | 1.42 | m/s | seviyelerine | çıktığı | gözlemlenmiştir.

Şekil 910-Araç Akış Analiz Simülasyonu

Şekil 9-Statik Analiz Tablosu

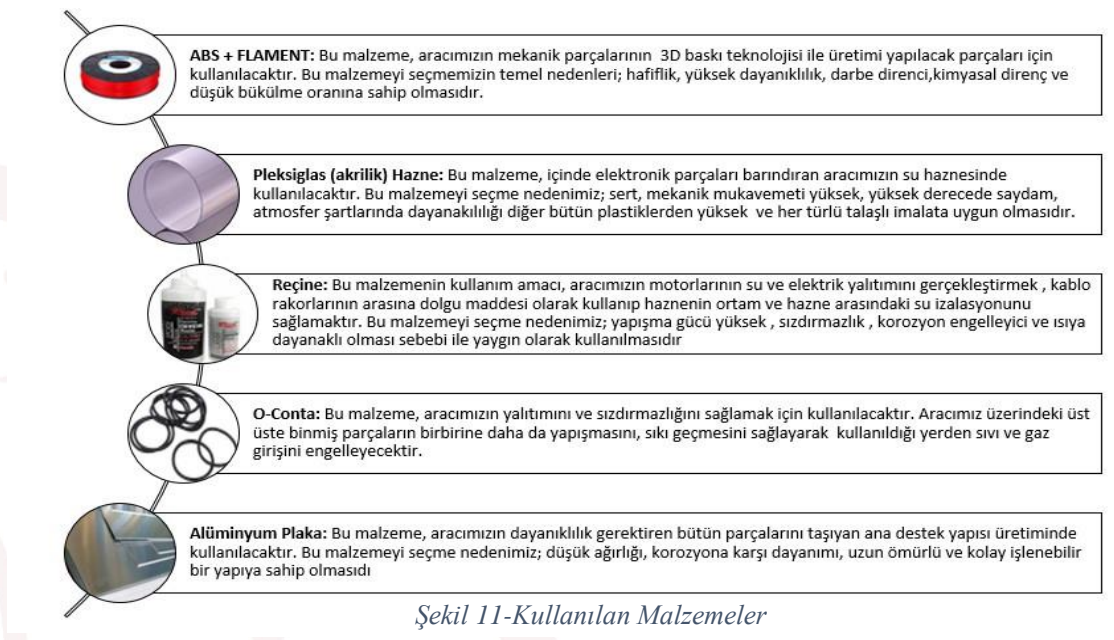
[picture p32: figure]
Şekil 11-Kullanılan Malzemeler

11

### 4.1.2. Malzemeler

### 4.1.3. Üretim Yöntemleri

### 4.1.4. Fiziksel Özellikler

3 Boyutlu Yazdırma: Mekanik ekibi tarafından bilgisayar üzerinde 3 boyutlu olarak tasarımı yapılmış malzeme modellerin, 3 boyutlu yazıcı teknolojisi ile üretilecektir. Bu üretim yöntemi için okulumuzun laboratuvarlarında bulunan endüstriyel üretimi yapabilmeye uygun özellikler taşıyan 3 boyutlu yazıcılar kullanılacaktır. Bu yöntem ile üretilecek parçalar ise şunlardır: Motor bağlantı elemanları, kuyruk, motor muhafazası, kabuk yapısı, pervaneler, ayaklar vb.

Tornalama Yöntemi: Bu işlem; dönme hareketi yapan silindirik iş parçası üzerinden, kesici takımın ilerleme hareketi yaparak talaş kaldırması prensibine dayanan ve araç için tasarlanan parçaların en azişçilik ve malzeme gereksinimleri minimum seviyede olmasını gerektiren bir üretim yöntemidir. Bu yöntem, aracımızın su geçirmez haznesinin ve kamera haznesinin flanşlarının üretimi için kullanılacaktır.

CNC Lazerle Kesim Yöntemi: Bu yöntem; güçlü bir lazer ışınının optik camlar ile yönlendirilmesi ve bu sayede ilgili metalin istenilen şekilde kesim veya kazıma işlemi yapılmasını sağlar. Bu yöntem ile aracımızın ana şase kısmının üretimi yapılması planlanmaktadır.

Delik Delme Yöntemi: Delik delme yöntemi, talaş kaldırarak dairesel delik elde etme üretim yöntemlerinden biridir. Araç üzerinde delik açılması gereken bölgeler için bu yöntem kullanılacaktır. Bu yöntem için okulumuzun laboratuvarlarında bulunan matkap tezgâhları kullanılacaktır.

Şekil 11-Üretim Yöntemleri

12

Şekil 12-Aracın Yüksekliği

Şekil 13-Aracın Boyu

Şekil 14-Aracın Eni

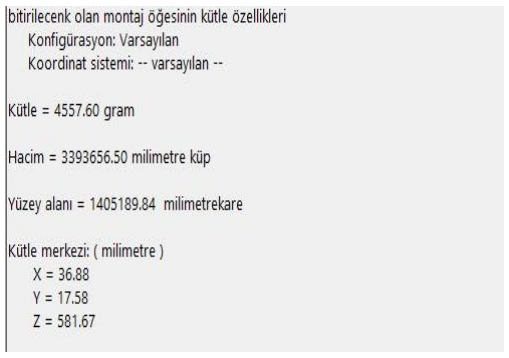
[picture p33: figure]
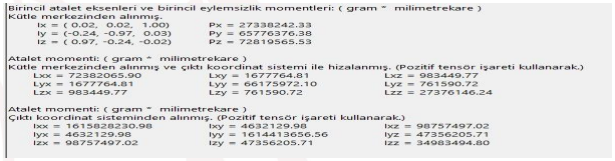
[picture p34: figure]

13

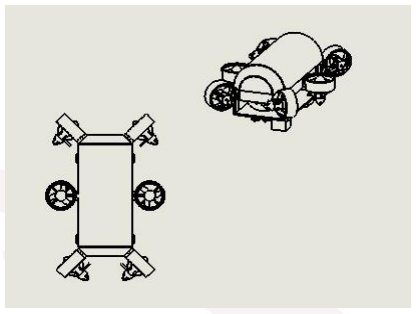
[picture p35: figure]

4.3.Elektronik Tasarım, Algoritma ve Yazılım Tasarımı

### 4.3.1. Elektronik Tasarım Süreci

Raspberry Pi 4 4GB : 4K ekran performansı, hızlı kod çözme yeteneği, hızlı CPU ve GPU özellikleri bulunan Raspberry Pi 4’ü ayrıca -50 °C ’lik sıcaklık değerine kadar çalışabildiği için aracımıza kullanmaya karar verdik.

LIDAR-Lite v3HP : Yüksek performanslı optik mesafe ölçüm sensörüdür. 5 cm ila 40 m aralığına sahiptir. LIDAR bir nesneye bir lazer vurarak ve daha sonra o ışığın sensöre dönmesi için geçen süreyi ölçerek çalışır. Aracımızda 2 Adet v3HP lidar kullanılmıştır.

Aracın Yüksekliği | 240mm
Aracın Boyu | 558.08mm
Aracın Eni | 384mm
Aracın Hacmi | 3393656.50 milimetre küp
Aracın Toplam Kütlesi | (4557.60 +1123.56) =5681,16 gram

14

TF03 (ToF) Laser Mesafe Sensörü – LIDAR : Toz geçirmez, suya dayanıklı, ‘’-25 ~ 60 ℃’’ çalışma sıcaklığı ve 180m’ye kadar ölçüm kabiliyeti nedeniyle ana LİDAR olarak aracımızın ön tarafında yer almaktadır.

Pixhawk 2.4.8 : Kullanacağımız programlama dili Phyton ile uyumlu çalışmakta olan Pixhawk 2.4.8 32 BİT, kullanacağımız sensörleri destekleyerek yazılım algoritmasını birleştirmemize yardımcı olacaktır.

Elektronik Hız Sürücüsü 30A ESC Çift Yönlü : Emsallerine göre küçük yapıda olması ile hacimden, hafif olması nedeniyle ise kütleden tasarruf etmiş olacağız.

Su geçirmez buton : Acil durumlarda aracımızın güç kesiminde kullanılacaktır.

Sızıntı Sensörü : Sızıntı sensörümüzde yer alan 4 farklı probu, su geçirmez haznemizin farklı noktalarında konumlandırarak olası bir sızıntıyı fark etmek ve diğer elektronik parçalarımız zarar görmeden müdahalede bulunabilmek için kullanacağız.

Derinlik Basınç Sensörü : Analog su basınç sensörü, bir steteskop gibi çalışarak suyun basıncını ölçmemize yarayacaktır.

G350 İnsansız Su Altı Rov İticisi – Thruster : G-350 içerisinde 350kv değerinde su geçirmez fırçasız motor kullanmaktadır bu sebeple uzun ömürlü ve dayanıklı olduğu için aracımızda kullanmaya karar verdik.

Gravity: BMX160+BMP388 10 DOF Sensör : Bir barometrik basınç sensörüdür. Yükseklik, tutum ve yönelimi ölçmek için aracımızda kullanılmaktadır. Çözünürlük: 0,3 µT Jiroskop: ± 125 ° / s ~ 2000 ° / s

Google coral geliştirme : Mikrodenetleyicilerimizi Programlamak amacıyla cihazımızda kullanılmıştır.

15

Emax ES08A II Mini Analog Servo motor : Mekanizmalardaki açısal-doğrusal pozisyon, hız ve ivme kontrolünü hatasız bir şekilde yaptığı için analog servo Motor tercih edilmiştir ayrıca bu modelimiz 23x11.5x24mm ölçüleriyle küçük ve gerekli torku sağladığı için aracımızda tercih edilmiştir.

ELP 100 Derece Bozulma Yok HD Kamera Modülü :Yeni sony IMX323 Renk Sensörü Serbest Sürücü 2MP Düşük Işık Kamerası USB H.264 1080P 30fps Geniş Açı USB Web Kamerası kullanılmıştır.

3S 12.6V 4A Li-ion & Lipo Pil Şarj Devresi : 3S Lityum Şarj edilebilir pilleri şarj etmeye olanak sağlayan devre. Pillerimizi type-c giriş ile kolayca şarj etmek için tercih edilmiştir.

Markalonya 5000mAh 3.7 V 26650 Li-lon şarj edilebilir pil: Fiyat Performans ve kapasite Açısından tasarruf etmek için li-ion şarj edilebilir pil tercih edilmiştir. 3S-5P bağlantı ve gerekli balanslama yapılmıştır. Toplam 25A ve 277,5Wh kadar Güç üretebilmektedir.

17HS4401 Nema 17 Step Motor: elektrik enerjisini dönme hareketi ile fiziksel enerjiye dönüştüren ve açısal konumu adımlar halinde değiştirebilen elektromekanik aletlerdir. Torpidoların ateşleme mekanizmasında kullanılmıştır.

Şekil 15-Elektronik Komponent Detayları

### 4.3.2. Algoritma Tasarım Süreci

Otonom sistemler için algoritma tasarımı, hata affetmeyen ve dikkatli bir yaklaşım

gerektiren kritik bir süreçtir. Tasarım aşamasında, donanımsal yetersizlikler ve ortam koşulları

gibi faktörlerin titizlikle değerlendirilmesi gerekmektedir. Zira gözden kaçan en ufak bir hata

veya eksiklik, görevin başarısızlıkla sonuçlanmasına sebep olabilir. Bu çalışmada, otonom su

altı aracımızın algoritma tasarım sürecini ele alıyoruz. Geliştirdiğimiz algoritmaların güvenli ve gerçeğe yakın bir şekilde test edilmesi amacıyla ROS (Robot İşletim Sistemi) kullanılmıştır.

Devam eden bölümlerde, algoritmaların detaylarını ele alacak ve aracın başarılı bir şekilde

görevini tamamlamasını sağlayan tasarım prensiplerini açıklayacağız. Görevin nasıl

gerçekleştirileceğini ve işe yarayıp yaramadığından bahsedeceğiz. Ancak herkes tarafından

bilinen işlemlerden ziyade görevin gerçekleştirilmesine yardımcı olan elzem unsurlardan

bahsetmenin daha öenmli olduğunu düşünmekteyiz. Bu sebeple her ne kadar kullanacak olsak

da geometrik şekil tespiti, yürütme, renk tespiti, konumlanma gibi koda dayalı algoritmalardan

4.3.3 Yazılım Tasarım Sürecinde bahsedeceğiz.

16

Havuz Taraması ve Görev Arama Algoritması:

Genel olarak algoritma Şekil 17’de görüldüğü gibi gerçekleşecek olan algoritmamız,

aracımızın gerçekleştireceği görevler için bir arama-tarama prosesi sunmakta. Araca başlat

komutu su geçirmez butonun açılması veya su üstü istasyonda gönderilecek bir sinyal ile başlar.

Araç, kendi ekseni etrafında dönerek üzerinde bulunan uzun menzilli LIDAR sensörleri

aracılığıyla havuzun iki boyutlu bir haritasını çıkaracak ve bu sayede hangi duvardan ne kadar

uzaklıkta olduğunu belirleyebilecektir. Aracın başlangıç konumu orijin olarak kabul edilecek ve üzerinde bulunan IMU (Ataletsel Ölçüm Birimi) sensörü aracılığıyla hangi yönde kaç derece

döndüğünü tespit edebilecek. Araç, hareket ettiği yönde ne kadar mesafe katettiğini bilerek,

IMU ve hareket bilgisi sayesinde konumundaki değişimini hesaplayabilecektir. Bu

hesaplamanın doğruluğu, LiDAR sensörleri aracılığıyla duvarlardan olan mesafenin

ölçülmesiyle teyit edilecektir. Tarama işlemi sırasında, belirtilen algoritmanın temel amacı,

taranan alanların tekrar tekrar taranmasını önlemek ve görev verimliliğini artırmaktır. Araç

tarafından algılanan hedeflerin, şekillerin veya renklerin konumları hafızada tutularak, gerçekleştirilen görev bölümlerinin tekrarlanmadan devam etmesi sağlanacaktır. Örneğin, araç,

daha önce geçtiği bir kapıdan tekrar geçmeyecektir. Bu algoritma, otonom araçların havuz gibi

karmaşık | ve | yapılandırılmış | ortamlarda | verimli | bir | şekilde | tarama | görevlerini

gerçekleştirmesine olanak sağlayacaktır. Bu algoritma her görev öncesinde çalışacaktır.

Şekil 16-Arama Algoritması

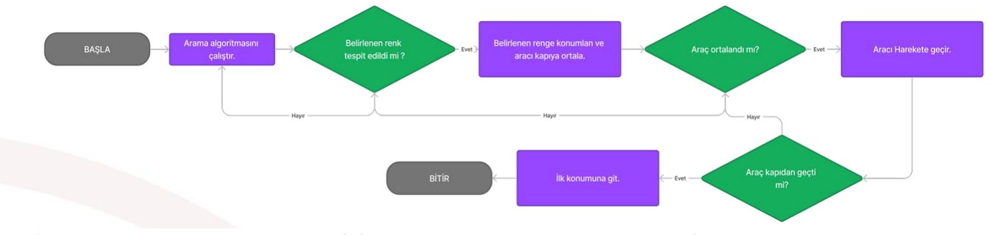
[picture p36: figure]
Şekil 18-Anomali Tespiti Algoritması

17

RENK Tespiti ve kapıdan geçiş görevi algoritması

Görevin gerçekleştirilmesi için öncelikle arama algoritması çalıştırılacak ve görevin

gereği içinden geçilmesi gereken kapıların ve renklerin tespit edilmesi gerekecektir. Ardından

tespit edilen kapılardan istenilen renge göre uygun olan kapının rengi Python ile opencv ve

numpy kütüphanelerini kullanarak yazdığımız kod bloğu çalışacak ve bize verilen renk koduna

göre belirlemiş olduğumuz renk aralığını sağlayan objeye doğru hareketlenecek, kenarlara

çarpmayacak şekilde konumlanacak ve içinden geçecektir. Geçip geçemediğini sorgulayarak

geçememiş ise tekrar tespit edip konumlanıp geçene kadar bu adımları tekrarlayacaktır geçiş başarılı olmuşsa ve araç görevin bittiğine karar vermişse başlangıç konumuna dönecektir (İsteğe

bağlı olarak bu eylemi gerçekleştirebilir.).

Burada ele alınması gereken önemli hususlar olarak rengin tespit edilerek hangi kapıdan

geçileceğine kara verilmesi kapının kenarlarına takılmadan geçişin sağlanması. Bu algoritmanın

gereği yazmış olduğumuz kodlar bunları sağlayabilecek kapasitededir simülasyonumuzda da

testi yapılmıştır.

Su Altı Kablo Takibi ve Anomali Tespiti

Şekil 19’da su altı kablolarının otonom olarak takip edilmesi ve üzerlerinde bulunan

anomalilerin tespiti için görüntü işleme ve derin öğrenme tekniklerini kullanan bir algoritma

Şekil 17-Renk Tespiti ve Geçiş Görevi Algoritması


18

önermekteyiz. Öncelikle kablo tespiti için arama-tarama algoritmamız çalışır. Aracın kendi

konumunu belirlemesini ve su altı kablosunu aramaya nereden başlayacağına karar vermesini

sağlar, görüntü işleme teknikleriyle kabloyu tespit eder. Kablo tespit edildikten sonra, aracın

kablonun ucunu bulup takip etmesi gerekir. Takip esnasında, önceden 10 farklı anomali türüne

ait görüntüler kullanılarak eğitilmiş bir derin öğrenme modeli, kablo üzerindeki anomalileri

tespit eder. Anomali tespiti için en uygun derin öğrenme modeli, veri seti elimize ulaştıktan

sonra belirlenecektir. KNN (K-En Yakın Komşu) veya Reinforcement Learning (Pekiştirmeli Öğrenme) algoritmaları, verinin boyutu ve temizliğine bağlı olarak potansiyel adaylar olarak

değerlendirilmektedir. Eğer veri seti yeterince büyükse Reinforcement Learning, daha az veri

içeren veri seti için ise KNN modeli tercih edilecektir. KNN modeli kullanılması durumunda,

görüntülerin daha detaylı ön işleme tabi tutulması ve her bir görüntünün manuel olarak

etiketlenmesi gerekecektir. Tespit edilen her anomali fotoğraflanır ve model tarafından hangi

anomaliye ait olduğu belirlenerek jüri üyelerine gösterilmek üzere hafızaya kaydedilir. Bu

esnada araç kablo takibine devam eder ve kablonun diğer ucuna geldiğinde görevin bittiğini anlayarak ilk konumuna geri döner. Önerilen sistem, tamamen görüntü işleme ve derin öğrenme

tekniklerine dayalı otonom su altı kablo takibi ve anomali tespiti imkanı sunmaktadır. Bu

sayede, su altı kablolarının bakımı ve onarımı daha hızlı, verimli ve güvenli bir şekilde

gerçekleştirilebilir.

Hedefe Torpido Fırlatma Görevi

Şekil 20’de, hedefe torpido fırlatma görevinde kullanacağımız algoritma görülmektedir,

özellikle küçük hedeflerin hassasiyetle vurulması amaçlanmıştır. Görevin gerçekleştirilmesi için

öncelikle arama tarama algoritması çalışır hedef çemberlerin tespiti sağlanır. Tespit edilen

çemberler arasından en küçük olanı seçilerek orta noktası hesaplanır ve ateşleme mesafesi bu

merkez noktaya göre otonom olarak ayarlanır. Torpidoları fırlatır.

Şekil 19-Torpido Fırlatma Görevi Algoritması

19

Görevin başarısı için küçük hedefin isabetli bir şekilde vurulması kritik öneme sahiptir.

Ancak, çemberlerin tespiti ve en küçük çemberin belirlenmesi aşamasında bazı yazılımsal

zorluklar ortaya çıkabilir. Bu zorluklardan en belirgini, araca göre sürekli olarak değişen

mesafeleri nedeniyle çemberlerin boyutlarının dinamik olarak değişmesidir. Yaklaştıkça

çemberler büyürken, uzaklaştıkça küçülürler. Bu durum, sabit bir yarıçap tanımlamayı

zorlaştırmakta. Bu sebeple konumlanmada da güçlük çekilmektedir. Bu problemin üstesinden

gelmek için, sürekli çember tespiti yerine belirli bir yakınlığa gelindiğinde, aralıklarla gözlem

yapılması önerilmektedir. Bu sayede, boyut problemi minimize edilebilir ve sistem en güncel

boyuta göre hedefi tespit edebilir. Belirli aralıklarla yapılan gözlemler sonucunda en küçük

çemberin konumu belirlenir ve araç bu konuma yönlendirilir. Bu yaklaşım, hedefe torpido

fırlatma görevinin hassasiyetini ve verimliliğini artırarak, özellikle küçük hedeflerin başarılı bir

şekilde vurulmasını sağlayacaktır.

### 4.3.3. Yazılım Tasarım Süreci

Aracımızda kuladığımız yazılımdili çoğunlukla Python olmakla beraber az da olsa

pixhawk üzerinden Mavlink protokolü için ve ROS Robot operating System için C programlama

dili kullanılmaktadır. Kullandığımız kütüphaneler görüntü işleme için; Pandas, Numpy,

OpenCv. Derin öğrenme için kullandıklarımız ise; Scikit-learn, Matplotlib kütüphaneleridir.

Hangi kütüphaneyi ne zaman kullandığımıza ilerleyen bölümde değineceğiz.

ROS Robot Operating System simülasyonların gerçekleştirilmesi için Gazebo ve Ardupilot

yazılımları ile entegre olarak Ubuntu 18.04 üzerinde sürüldü. Bu bölümde görülen bütün simülasyon

görüntüleri Ubuntu 18.04 te ROS üzerinden gerçekleştirilmiştir. Bu simülasyon ortamı esasen

yazılım ve algoritmaların ne kadar tutarlı olduğunun denetlenmesi için kullanılsa da eklediğimiz

kütüphaneler sayesinde gerçeğe yakın fiziki koşulları da sağlamaktadır. Bu sayede aracı suya

indirmeden algoritma, yazılım ve torpido atışının isabetinin ne derece kullanışlı olduklarını test

edebilme imkânına sahibiz.

ARAÇ Yazılımında Kullanılan Teknolojiler ve Simülasyon Ortamı:

20

Geliştirdiğimiz yazılımlarda ağırlıklı olarak Python programlama dili kullanılmaktadır. Python, otonom sistemler geliştirmek için ideal bir dil haline gelen bir dizi özellikle öne çıkıyor. Kolay öğrenilen sözdizimi ve zengin kütüphane ekosistemi, karmaşık sistemlerin hızlı prototiplenmesini ve geliştirilmesini sağlar. Özellikle derin öğrenme alanında TensorFlow ve PyTorch gibi kütüphaneler, gelişmiş algoritmaların uygulanmasını ve eğitilmesini kolaylaştırarak otonom sistemlerin karmaşık karar alma mekanizmalarını oluşturmayı oldukça kolaylaştırıyor. Bununla birlikte, Pixhawk üzerinden MAVLink iletişimi, ROS (Robot Operating System) entegrasyonu ve ROS kütüphane güncellemeleri için C dili de kısmi olarak kullanılmakta. Görüntü işleme süreçlerinde faydalandığımız kütüphaneler:

Pandas: Veri analizi ve manipülasyonu için güçlü ve esnek bir kütüphanedir. Özellikle tablo

biçimindeki | verileri | işlemek, | temizlemek | ve | analiz | etmek | için | kullanılır.

NumPy: Bilimsel hesaplamalar için temel bir kütüphanedir. Çok boyutlu diziler ve matrisler

üzerinde işlem yapma, lineer cebir, Fourier dönüşümü gibi işlemleri gerçekleştirme imkanı

sunar.

OpenCV: Açık kaynak kodlu bir bilgisayar görüsü ve görüntü işleme kütüphanesidir. Görüntü

ve video verilerini analiz etme, nesne tanıma, özellik tespiti gibi işlemleri gerçekleştirmek için

kullanılır.

Derin | öğrenme | uygulamalarında | kullanacak | olduğumuz | kütüphaneler | ise:

Scikit-learn: Makine öğrenmesi algoritmaları ve araçları sunan bir kütüphanedir. Sınıflandırma,

regresyon, kümeleme gibi işlemleri gerçekleştirmek için yaygın olarak kullanılır.

Matplotlib: Veri görselleştirme için kapsamlı bir kütüphanedir. Grafikler, histogramlar gibi

çeşitli görseller oluşturarak verileri anlamak ve sunmak için aynı zamanda eğitilen modelin test

aşamasının ardından ne kadar vermili olduğunu anlamak için kullanılacaktır.

ROS tabanlı simülasyonlar, Gazebo ve ArduPilot yazılımları ile entegre olarak Ubuntu 18.04

işletim sistemi üzerinde gerçekleştirilmiştir. Bu bölümde sunulan tüm simülasyon görüntüleri,

Ubuntu 18.04 üzerinde ROS ortamında hazırlmaış olduğumuz simülasysonlardan kesitlerdir. Söz

konusu simülasyon ortamı, temelde yazılım ve algoritmaların doğrulanması amacıyla kullanılsa da,

entegre edilen kütüphaneler sayesinde gerçekçi fiziksel koşulların simülasyonunu da mümkün

kılmaktadır. Bu sayede, araç suya indirilmeden önce algoritmaların ve yazılımların etkinliği test

edilebilmektedir.

Kullandığımız görüntü işleme algoritmalarına dayalı kod blokları ve uygulama görselleri:

Kare dikdörtgen gibi 4 köşeli görselleri tespit etmek için kullandığımız görüntü işleme kodu. Burada dikkat çeken özellik olarak canny algoritmasından bahsedilebilir, görüntülerdeki kenarları tespit etmek için kullanılan güçlü bir yöntemdir. İki eşik değeri (canny1 ve canny2) kullanarak zayıf ve güçlü kenarları belirler. Düşük eşik (canny1), daha fazla kenarı yakalarken, yüksek eşik (canny2) sadece belirgin kenarları seçer. İki eşik arasında kalan pikseller ise güçlü

21

bir kenara bağlılarsa kenar olarak kabul edilir. Trackbarlar ile bu eşikleri ayarlayarak, ortam koşullarına uygun en iyi kenar tespiti sağlanır. Ancak, Canny algoritması mükemmel düz çizgiler üretmeyebilir. Bu nedenle, "approx" değeri, kenarları basitleştirmek ve düz çizgi parçalarına yaklaştırmak için kullanılır.

Renk Tespiti Algoritması:

OpenCV ve NumPy kütüphaneleri, görüntülerde belirli renkleri tespit etmek için güçlü araçlar

sunar. Aşağıdaki kod parçacığı, kırmızı renk aralığındaki pikselleri tespit etmek için bu kütüphaneleri

nasıl kullanabileceğinizi göstermektedir. RGB renk kodları kullanılarak kırmızı rengin alt ve üst sınırları

belirlenir. Bu sınırlar, görev gereksinimlerine ve verilen renk koduna göre ayarlanabilir. Renk tespiti,

belirlenen bu aralıkta kalan pikselleri filtreleyerek gerçekleştirilir. OpenCV'nin inRange() fonksiyonu,

belirtilen alt ve üst sınırlar arasında kalan pikselleri tespit ederek, kırmızı renkli bölgeleri etkili bir

şekilde vurgular. Bu yöntem, farklı renkleri tespit etmek için, sadece renk aralığını değiştirerek kolayca

uyarlanabilir.


22


Araç Kontrol Komutları:

Görselde görüldüğü üzere, ArduSub yazılımı ve GazeboRos simülasyon ortamı kullanarak aracımızın kontrol modülü ele alınmaktadır. Aracın gerçekçi bir şekilde simüle edilmesi için Gazebo ortamında Roscore ile entegrasyon sağlanmıştır. Kontrol komutlarının iletimi ise ArduSub yazılımı üzerinden gerçekleştirilmektedir. Bu amaçla, aracın otonom olarak hareketleri yönlendirmek için belirli kanal değerlerinin ayarlanması gerekmektedir. Çalışma kapsamında, rover'ın GazeboRos ortamında gerçeğe yakın fiziki koşullar altında simüle edilmesi ve kontrol komutlarının etkin bir şekilde iletilmesi hedeflenmektedir.

Şekil a | Şekil b

Şekil a'da görüldüğü üzere, simülasyon ortamımızda bulunan su altı aracımız çember tespit algoritmasını başarılı bir şekilde gerçekleştirmektedir. Benzer şekilde, Şekil b'de aracın kare/dikdörtgen algılamada da başarılı olduğu ve kareleri doğru bir şekilde tespit edebildiği gözlemlenmiştir.

Simülasyon ortamımız, Şekil a ve b'de gösterildiği gibi, beklenen görevleri yerine getirebilecek şekilde yapılandırılmıştır. Havuz içerisinde 3 farklı boyutta çember, 3 farklı renkte dikdörtgen kapı ve üzerinde çeşitli geometrik şekillerle oluşturulmuş anomalilere sahip bir halat bulunmaktadır. Bu simülasyon ortamı, aracı suya indirmeden önce yazılımların güvenli bir şekilde test edilmesine olanak tanımaktadır.

23

### 4.4. Dış Arayüzler

Aracın donanım bağlantılarını ve görevler için yüklenecek paketlerin kolay bir şekilde yönetilmesini sağlamasının yanında TYF’den farklı olarak değişen donanımlarımıza uygun bağlantıların kaynak paketlerini ekleyerek arayüzü güncelledik. Bunun yanında Raspberry pi 4 içerisindeki SD kartta bulunan log kayıtları da arayüz de gösterilecektir.

Dikdörtgen Şeklin Tespit Süreci

Bir görüntüdeki kare veya dikdörtgen alanı tespit etmek için öncelikle görüntüdeki tüm konturları tespit ettikten sonra, konturlar arasında döngüler kurulur ve yaklaşık kontur sayısı bulunur. Yaklaşık konturdaki köşe noktası sayısı 4 ise, dikdörtgen ve kare arasında bir fark yaratmak için en boy oranını hesaplarız. En boy oranı 1 den farklıysa şeklin dikdörtgen olduğunu söyleyebiliriz.

OpenCV kütüphanesini python dosyamıza import ettikten sonra “cv2.imread()” fonksiyonu kullanılarak giriş görüntüsü okunur ve “grayscale”e çevrilir. İkili bir görüntü oluşturmak için gri tonlamalı görüntüye eşikleme uygulanır. Daha iyi bir kontur algılama elde etmek için parametre ayarlamaları yapılır. “cv2.findContours” fonksiyonu kullanılarak görüntüdeki konturlar bulunur. Konturlardaki “cnt” nin en boy oranı hesaplanır. “Approx” değeri 4 ve en boy oranı 1 ise bu şekil kare aksi takdirde dikdörtgendir.


Kod bloklarında yer alan kare2.png dosyası verildiğinde, çıktı olarak şekil’de görüldüğü gibi kare ve dikdörtgen alan tanınmıştır.


24

Uygulama | aşmasında | edinilen | deneyimler | söz | konusu | görevlerin başarılı bir | şekilde
gerçekleştirilebilmesi için bizlere yapabileceğimiz gerekli geliştirmeleri görmemize yardımcı olacaktır. Bu sayede sağlıklı bir yazılım geliştirilmesinde önemli rol oynamaktadır.

### 5. GÜVENLİK

- Danışman hocamız tarafından tüm ekip üyelerine iş sağlığı ve güvenliği eğitimi

verilmiştir.

- Tüm ekip üyelerine koruyucu gözlük ve antistatik eldiven temin edilmiştir.
- Çalışma ortamında yangın tüpü ve ilk yardım çantası bulundurulmaktadır.
- Araç tasarımında keskin hatlar yerine radyuslu yapılar tercih edilerek oluşabilecek

yaralanmaların önüne geçilmiştir.

- Acil durum butonu, aracımızın ön tarafında konumlanacak ve herhangi bir güvenlik

ihlali oluştuğu takdirde hızla aracımızın enerjsini kesebilmeye yarayacaktır.

- Elektrik birimimiz laboratuvarda yaptığı tüm çalışmalarda antistatik bileklik

kullanmıştır.

### 6. TEST


25

Yapmış olduğumuz algoritmaların, bizden istenen renk ve konumlandırma görevlerini yerine getirip getirmediğini tespit etmek amacıyla bilgisayar ortamında kurduğumuz similasyon ile algoritmalarımızı test ettik.

Araç Sızdırmazlık Testi: Aracımız olimpik havuzda sızdırmazlık testine tabi tutulmuş ve su yüzeyine hava kabarcığı çıkarmadığı gözlemlenmiştir.

Araç Hareket Kabiliyet Testi: Aracımızın sualtında bir noktadan başka bir noktaya dengeli bir şekilde hareket edebilmesi test edilmiş ve başarıya ulaşılmıştır.


### 7. TECRÜBE


2022 KTR tasarımımızda, kamera yapımız pleksiglas kubbe şeklinde olup sualtı testleri sonucunda

kamera görüntüsünün kubbemsi yapıdan dolayı kırıldığı ve net bir görüntü elde edilemediği bu yüzden

de görevleri gerçekleştirirken aracımızın yanlış komutlarda hareket ettiği görüldü. Bu nedenle yeni araç

tasarımımızda daha geniş açılı ve net bir görüntü elde etmek için dalgıç kamerası kullanılmasına karar

verildi. Daha önce üretimi planlanan ve su geçirmez haznemizin tabanında bulunan kamera kubbesinden

de bu yüzden vazgeçilerek farklı bir kamera konumlandırmasına gidildi.

2022 KTR tasarımımızdaki araç yapımızda 3D yazıcılarla basılmış parçalar bulunmaktaydı. Parçalar

3D yazıcı ile basılırken parça doluluk oranı göz önüne alınmadığından hafif ve mukavemeti düşük parça

elde edildi. Parçaların hafif ve gözenekli olmasından dolayı aracımız suya batmakta zorlanıyordu. Bu

nedenle yeni tasarımda 3D basımında doluluk oranları dikkat alındı. Buna ek olarak yeni tasarımda

aracımızın ayak yapısını alüminyum malzeme ile üreterek ayaklarda mukavemeti arttırmak ve suya

dalışları kolaylaştırmak hedeflendi.

2022 KTR tasarımımızın montajında akım koruma devreleri bulunmadığı için elektriksek devrelere

fazla yük binmesi sonucu araç içerisinde ısı artışından dolayı kablo yalıtkanlarında koku yayılımı olduğu

fark edildi. Bu aşırı ısınma ile hazne içerisinde bulunan sistem ve sensörlerin zarar görmemesi için akım

koruma devreleri ve bu akım koruma devreleriyle birlikte daha iyi bir kablolama sisteminin

kullanılmasına karar verildi.

26

### 8. ZAMAN, BÜTÇE VE RİSK PLANLAMASI

Şekil 21-Zaman Planlaması

Şekil 20-Bütçe Planlaması


27

Şekil 22-Risk Planlaması

### 9. ÖZGÜNLÜK

Yazılım Birimi Özgünlük Raporu

Oluşturmuş olduğumuz bütün algoritmalar mekanik, elektronik ve yazılım ekibi tarafından

ortak çalışma sonucu oluşturulmuş olup herhangi bir ekibin hareketinin diğer ekibi

kısıtlamadan, her bir birim için çalışma alanı sınırları içerisinde kararlar verilerek belirlenmiştir. Örneğin lidarların konumu, basınç sensörüne muhafaza eklenerek sensörün dinamik basınçtan

etkilenmemesi ve yalnızca ihtiyacımız olan statik basıncı ölçerek yazılım için derinlik hakkında

daha tutarlı veriler üretebilmesi sağlanmıştır. Kameralar, görüntüyü verimli bir şekilde

alabilmeleri için doğru konumlandırılmış ayrıca menzili tarayabilen gerekli açılarda


28

yerleştirilmiştir. Bu bahsedilen aşamalar genel olarak yazılımda planlama, analiz ve tasarım

adımlarının diğer birimler ile iş birliği içerisinde yapıldığına örnek teşkil etmektedir.

Yazılımımızı benzersiz yapan birçok unsur olmak ile beraber bunlardan en belirginleri; mekanik

birimi ile ortak olarak geliştirdiğimiz kuyruk yapısı, basınç sensörünün önüne bir kubbe

şeklinde çeper konulması, lidarların birbirinin devamı şeklinde konularak yazılımda tek bir 3

boyutlu matrisin panoramik verisinin elde edilmesi, aracımızın altında bulunan zemin tarama

ve merkez hesaplamada kullanılacak olan kameranın eklenmesidir.

Yunus ve çekiç başlı köpek balığından esinlenilerek mekanik ekibimiz tarafından oluşturulan

tasarıma kuyruk eklenmesi ve bu kuyruk yapısının eklenmesindeki getirisi; hedef tespiti ve

imhası görevinde, pingerli hedefe nişan alarak hangi konumda bulunduğunun önemi olmaksızın

kuyruk yönlendirmesi ile hedefe çarpması olacaktır. Aynı zamanda motorlar, kuyruk açısı,

aracın atalet katsayısı, basınç sensöründen gelen derinlik bilgileri ve pingerden gelen sinyallerin

eş zamanlı olarak gecikmesiz bir şekilde tek algoritmada hatasız bir şekilde işlenebilmesinin

sağlanması, bizim aracımızı özgün yapan yegane unsurdur.

### 10. YERLİLİK

ATILAY takımı olarak en önemli hedeflerimizden biri; aracın üretimini yerli ve milli imkanlarla yapabilmektir. Türkiye'nin ekonomik ve teknolojik bağımsızlığını temin edecek yegane vizyonu olan Milli Teknoloji Hamlesi‘nden yola çıkarak meydana

Şekil 23-Mekanik Birimi Özgünlük Notları

29

getirdiğimiz aracımızda bulunan yerli kısımlar şu şekildedir:

- Aracın koruma elemanları olan sigorta, acil durum butonu, röle ve su altı kamerası yerli firmalardan temin edilmiştir.
- Kullanılacak olan motor sürücüsü (ESC), basınç sensörü ve güç dağıtım kartının yerli firmalardan alınmıştır.
- Özgün bir şekilde tasarımı yapılan alüminyum plaka şasinin imalatı yerli bir şekilde yapılmıştır.
- Oluşturduğumuz aşırı akım koruma devresi, okulun atölyesinde yerli ve milli
bir şekilde takımın imkanlarıyla üretilmiştir.
- Aracın elektrik aksamlarını içinde bulunduran muhafaza tüpünün üretimi % 100 yerlidir.
- 2 ve 3 kanatlı olmak üzere 3 farklı pal tasarımı gerçekleştirilmiştir. 2 kanatlı pal genellikle en yüksek hız performansı sağlarken, 3 kanat paller ise maksimum
itme ve görece düzgün seyir operasyonu sağlamaktadır. Gerekli testler ve analizler yapılarak en uygun pal seçimi yapılacaktır. Ayrıca motor pallerimizi satın almak yerine motorumuza uygun olarak tasarlayıp 3D yazıcılar ile üretimini yaptık.

30

### 11. KAYNAKÇA

1. Yılmaz. S, Yakut. M, İnce.S, “Derinlik ve Yön Kontrol Uygulamaları için Deney Platformu

Tasarımı”,Tübitak 1002 Hızlı Destek Projesi Final Raporu, Proje No:111E294, Temmuz 2013.
2. Kırcı.H, Yılmaz.S, Yakut. M, “İnsansız Sualtı Araçları”,Endüstri & Otomasyon Dergisi, 134,

24-29 , 2008

3. Kyriakidis. M, et al., “Public opinion on automated driving: Results of an international

questionnaire among 5000 respondents”, Transport Res F-Traf, vol. 32, pp. 127–140, 2015.

4. Hovem. J. M , Marine Acoustics: The Physics Of Sound In Underwater Environments.

Peninsula publishing Los Altos Hills, 2012.

5. Edge. M, The Underwater Photographer, 2nd edition. Butterworth-Heinemann, 1999.
6. Wernli. R, “Operational Effectiveness of Unmanned Underwater Systems”, Marine

Technology Society, 1998.

7. Drucker.E. G, and Lauder. G. V, Locomotor function of the dorsal fin in teleost fishes:

experimental analysis of wake forces in sunfish. J. Exp. Biol.204, 2943-2958 (2001).

8. Ferry. L. A, and Lauder. G. V, Heterocercal tail function in leopard sharks: a threedimensional

kinematic analysis of two models. J. Exp. Biol.199, 2253-2268 (1996).

9. Q.R.Zhang, P.Peng, Y.M.Jin, “Cherry Picking Robot Vision Recognition System Based on

OpenCV”, MATEC Web of Conferences, January 2016.

10. Garcia. J. M. M, Trincado. J, Sanchez. J, "Analysis of sensor data and estimation output

with configurable UAV platfo1ms," 2017 Sensor Data Fusion: Trends, Solutions, Applications

(SDF), Bonn, 2017, pp. 1-6.

11. Milne. P.B, Underwater Acoustic Positioning Systems. E. & F. N. Spon Ltd, 1983.
12. İlten. E, Eker.K.M, “PIC Mikrodenetleyici Tabanlı Otomatik Voltaj Regülatörü

Tasarımı”TMMOB EMO ANKARA ŞUBESİ HABER BÜLTENİ 2012/3

### 13. Akdağ. O, Yeroğlu. C, “Güç Sistemlerinde Aşırı Akım Koruma Koordinasyon

### Modelinin Oluşturulması, Benzetimi ve Optimizasyonu”, Fen Bilimleri Enstitüsü Dergisi

### ISSN: 1307-9085, e-ISSN: 2149-4584, 2019, 12(1), 202-214

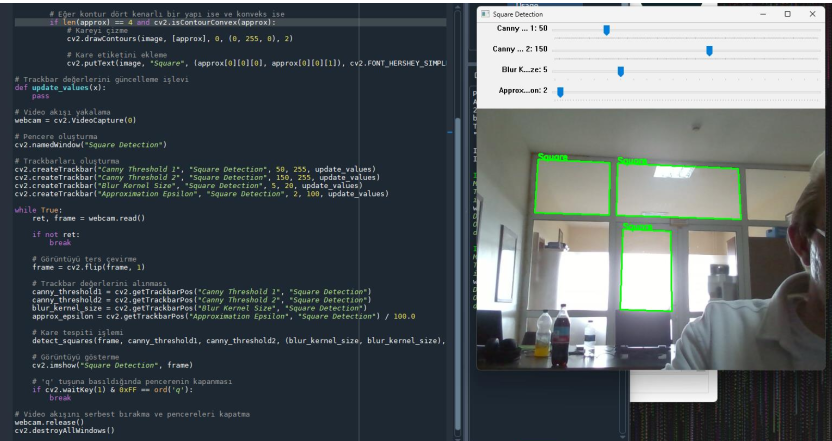
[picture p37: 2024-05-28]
images/dikdortgen_tespit.png

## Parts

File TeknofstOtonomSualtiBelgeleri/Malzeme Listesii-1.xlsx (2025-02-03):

Ürün Adı | Ürün Açıklaması (Teknik Özellikleri | Ürün Linki | Adet | Birim Fiyatı (TL) | Tutar (TL) | Alternatif Tedarikçi
Tower Pro MG995 Yüksek Torklu Servo Motor - 360 Derece | Çalışma Voltajı: 4,8 ~ 7.2V/DC Taşıma Kapasitesi: 12KG Dönme Açısı: 360 Derece Rulman Tipi: Rulman Yok Dişli Tipi: Metal Dişli | https://www.direnc.net/ds3120mg-su-gecirmez-servo-motor | 1 | 968.78 | 968.78
TF03 (ToF) Lazer Mesafe Sensörü - LIDAR (180m) | Menzil – 180m@% 90 yansıtma, 70m @% 10 yansıtma Tespit edilmeyen bölge – 10cm Mesafe çözünürlüğü – 1cm Doğruluk - ± 10cm (10m'den az),% 1 (10m'den fazla) Tekrarlanabilirlik – 1σ ： <3cm | https://www.robotistan.com/tfmini-plus-uzun-mesafe-lidar-modulu | 1 | 11233.17 | 11233.17
LIDAR-Lite v3HP - Lidar Mesafe Sensörü | Menzil - 180m @% 90 yansıtma, 70m @% 10 yansıtma Tespit edilmeyen bölge - 10cm Mesafe çözünürlüğü - 1cm Doğruluk - ± 10cm (10m'den az),% 1 (10m'den fazla) Tekrarlanabilirlik – 1σ ： <3cm | https://www.robotistan.com/lidar-lite-v3hp | 2 | 8386.76 | 16.773,52
Readytosky 5V/2A 30A Drone ESC Banana Konnektörlü | ESC | https://www.dronmarket.com/urun/readytosky-5v-2a-30a-drone-esc-banana-konnektorlu?hsa_acc=5529338403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 | 7 | 377.5 | 2642.5
Gravity: BMX160+BMP388 10 DOF Sensör | Çalışma Aralığı300-1250 hPa Çözünürlük0.3μT Jiroskop± 125 ° / s ~ 2000 ° / s Jeomanyetik Sensör± 1150uT (x-, y ekseni); ± 2500uT (z ekseni) | https://www.direnc.net/gravity-bmx160bmp388-10-dof-sensor | 1 | 928.41 | 928.41
LentaMarine G-350 304 serisi | 12-25V Yüksek itiş ücüne sahip | https://www.shopier.com/ShowProductNew/products.php?id=12376721 | 7 | 2750 | 19250
Molicel INR-18650-P28A - 3.7V 2800 mAh Li-ion Şarjlı Pil -35A | 3.7V 2800 mAh Li-ion şarj edilebilir pil | https://www.n11.com/urun/markalonya-5000-mah-37-v-26650-li-ion-sarj-edilebilir-pil-25104145?magaza=pilstore | 15 | 239 | 3585
Sualtı Robot derinlik sensörü su derinliği basınç yüksek hassasiyetli düşük güç tüketimi MS5837 açık kaynak B30 | Su altı hassas basınç sensörü | https://www.shopier.com/ShowProductNew/products.php?id=23727125 | 1 | 2500 | 2500
Arducam 12MP 3840(H)×3032(V) USB Kamera Modülü 4K@30fps M12 Lens, Raspberry Pi için Manuel Odaklı USB Kamera | Kamera | https://www.amazon.com.tr/Arducam-Kamera-Mod%C3%BCl%C3%BC-Raspberry-Manuel/dp/B0C1G73QZD | 1 | 3539.96 | 3539.96 | https://www.arducam.com/product/12mp-usb-camera-module-with-m12-lens-1-2-3-3840hx3032v-4k30fps-for-windows-linux-macos-and-android/
XHE20 6 Pin Su Geçirmez Konnektör Takım IP67 | Pin Sayısı6 PinAnma Gerilimi500vAnma akımı15APanel Diş Çapı21 mm | https://www.direnc.net/xhe20-6-pin-su-gecirmez-konnektor-takim-ip67 | 10 | 3831.5 | z
Hobimekatronik 3S 50A Bms 12.6V 18650 Lityum Lipo Pil Şarj Koruma Modülü |  | https://www.amazon.com.tr/12-6V-18650-Lityum-Koruma-Mod%C3%BCl%C3%BC/dp/B0BT4WDR16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 | 2 | 203.22 | 406.44 | https://www.hobimekatronik.com/urun/3s-50a-bms-12-6v-18650-lityum-lipo-pil-sarj-koruma-modulu
Viofo Fuse Tap Sigorta Kutusu Bağlantı Aparatı 4'lü |  | https://www.amazon.com.tr/Viofo-VFT6-Fuse-Tap-K%C4%B1rm%C4%B1z%C4%B1/dp/B08293J6XZ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 | 2 | 238.41 | 476.82 | https://www.maxitekno.com/viofo-fuse-tap-sigorta-kutusu-baglanti-aparati-4lu-3355
JOREST 160 parça araba sigorta seti, 96 mini bıçak sigortaları+64 standart araba sigortaları+1 sigorta çektirme - arabalar/motosiklet, motosiklet için (2 amper 3A 5A 7.5A 10A 15A 20A 25A 30A 35A 40A) |  | https://www.amazon.com.tr/JOREST-sigorta-sigortalar%C4%B1-standart-%C3%A7ektirme/dp/B093L93DRC | 1 | 297.86 | 297.86 | https://www.babligo.com/urun/bicak-sigorta-seti-100lu
Sarf Malzeme | 3D Yazıcı flament Epoksi kaplama Bağlantı eleman ve ekipmanları Kablolar |  | 1 | 17986.46 | 17986.46
 |  |  |  | Genel Toplam: | 84,420.4

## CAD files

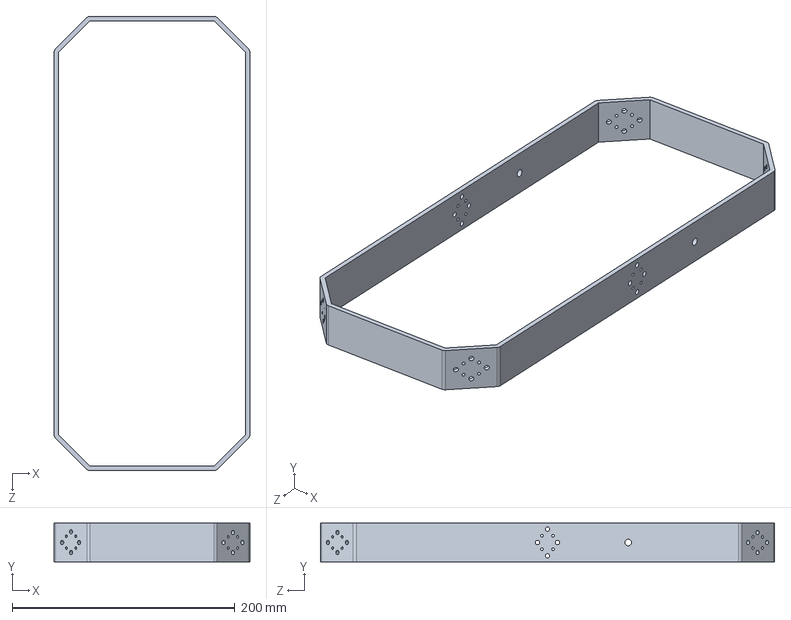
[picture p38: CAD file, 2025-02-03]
DenizAltiTasarimDosyalari/şase yeni.SLDPRT
176.0 x 35.0 x 408.0 mm

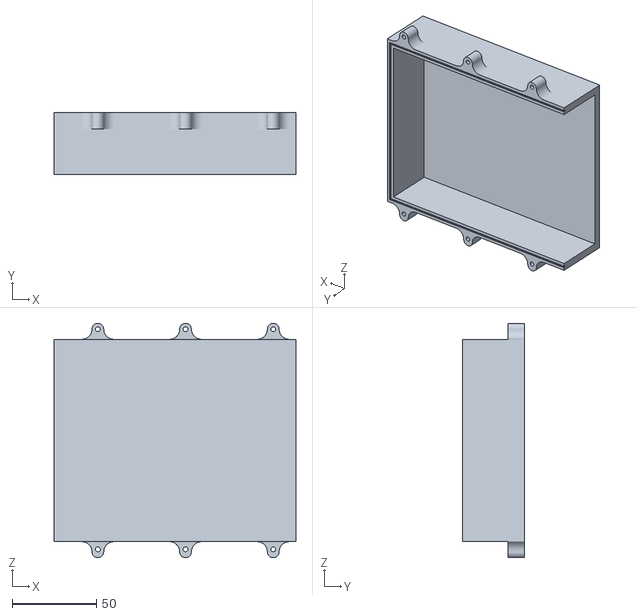
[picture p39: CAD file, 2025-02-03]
DenizAltiTasarimDosyalari/bataryayeni_kap1.2.STL
143.5 x 37.0 x 139.0

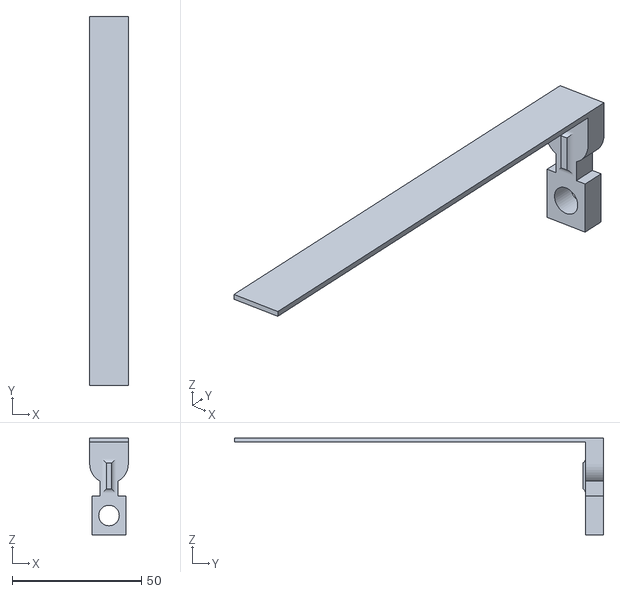
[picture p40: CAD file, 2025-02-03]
DenizAltiTasarimDosyalari/yeni step yay arası parça.STL
15.0 x 143.0 x 37.5

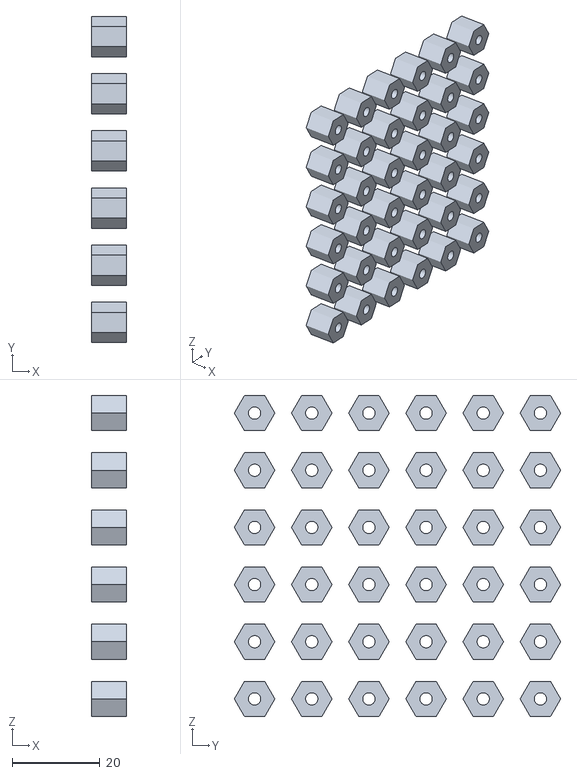
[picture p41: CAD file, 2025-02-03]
DenizAltiTasarimDosyalari/ara çubuklar 2.STL
8.00 x 74.2 x 73.0

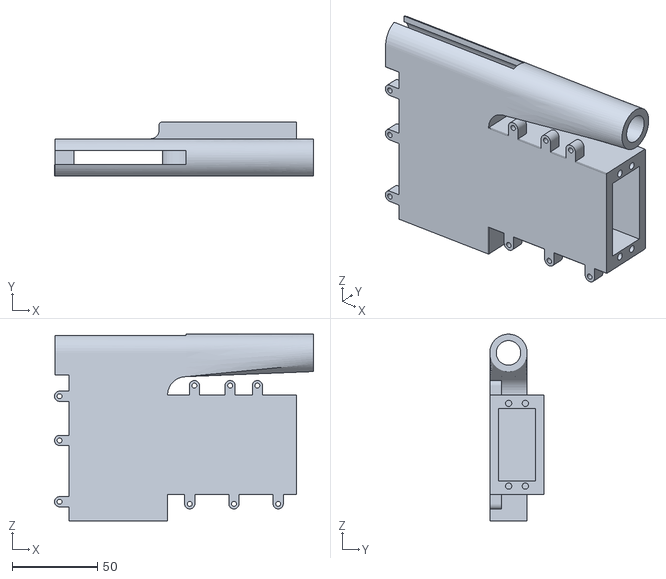
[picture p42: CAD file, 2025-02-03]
DenizAltiTasarimDosyalari/enozelsilah1.2.1.STL
152.2 x 32.0 x 109.8

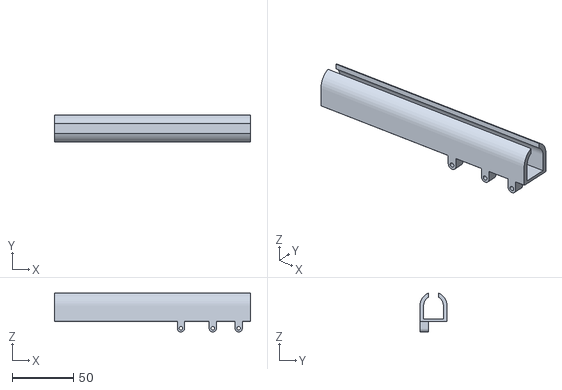
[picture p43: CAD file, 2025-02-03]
DenizAltiTasarimDosyalari/enpzelsilah1.2.12.STL
159.7 x 22.0 x 31.7

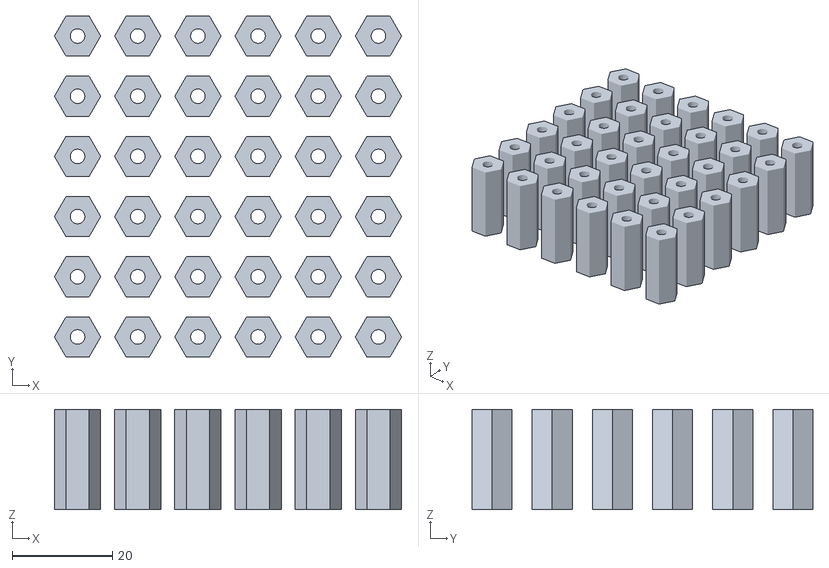
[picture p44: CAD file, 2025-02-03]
DenizAltiTasarimDosyalari/cubuklar uzun 2.9.STL
69.2 x 68.0 x 20.0

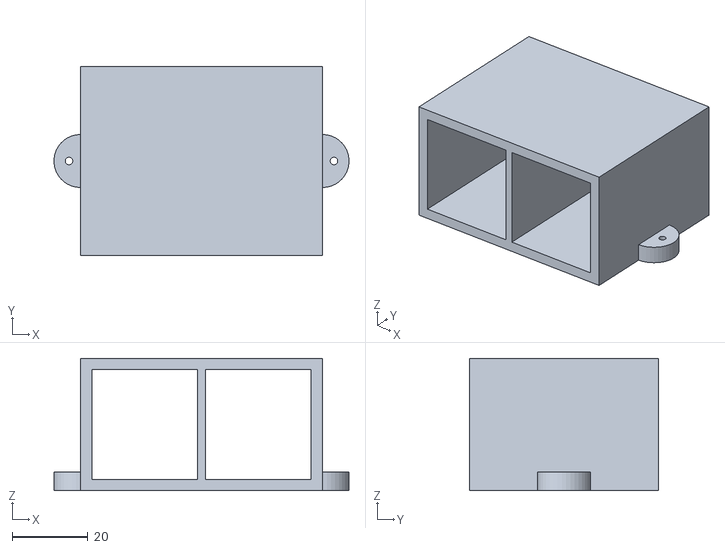
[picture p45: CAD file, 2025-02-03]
DenizAltiTasarimDosyalari/esc kutusuÖMERE AT.STL
78.0 x 50.0 x 35.0

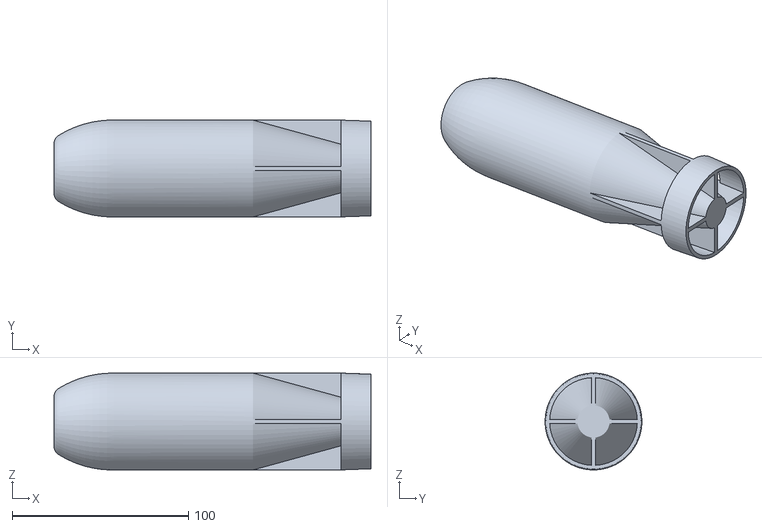
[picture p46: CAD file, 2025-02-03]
DenizAltiTasarimDosyalari/torpido1.2.1.STL
180.0 x 55.0 x 55.0

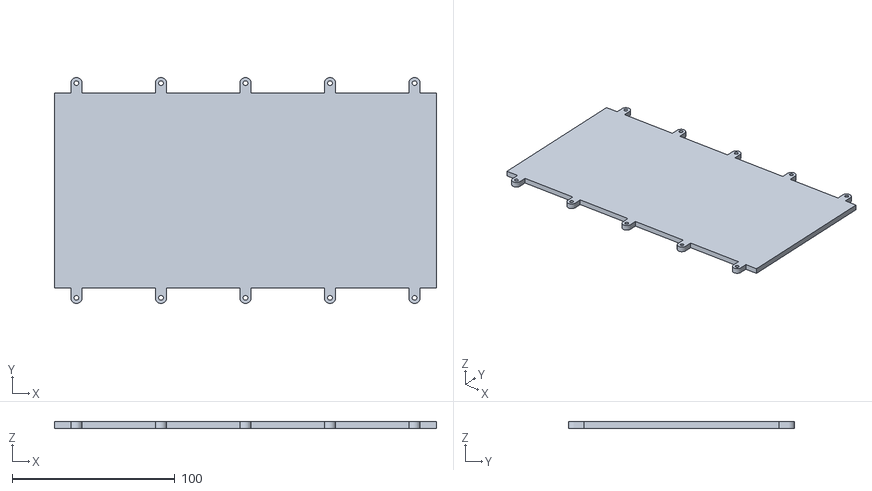
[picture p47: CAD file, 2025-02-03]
DenizAltiTasarimDosyalari/bataryayenikabi.STL
235.0 x 139.0 x 4.00

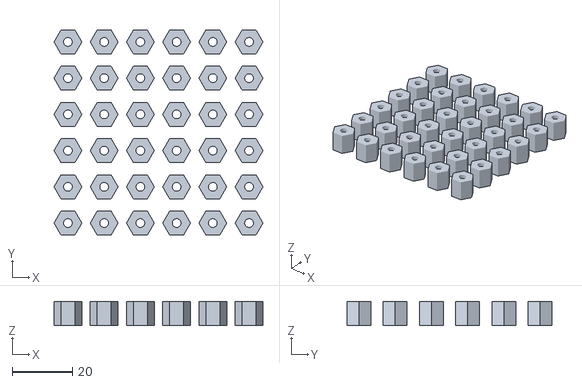
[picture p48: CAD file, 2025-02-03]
DenizAltiTasarimDosyalari/yeni çubuklar 2.9.STL
69.2 x 68.0 x 8.00

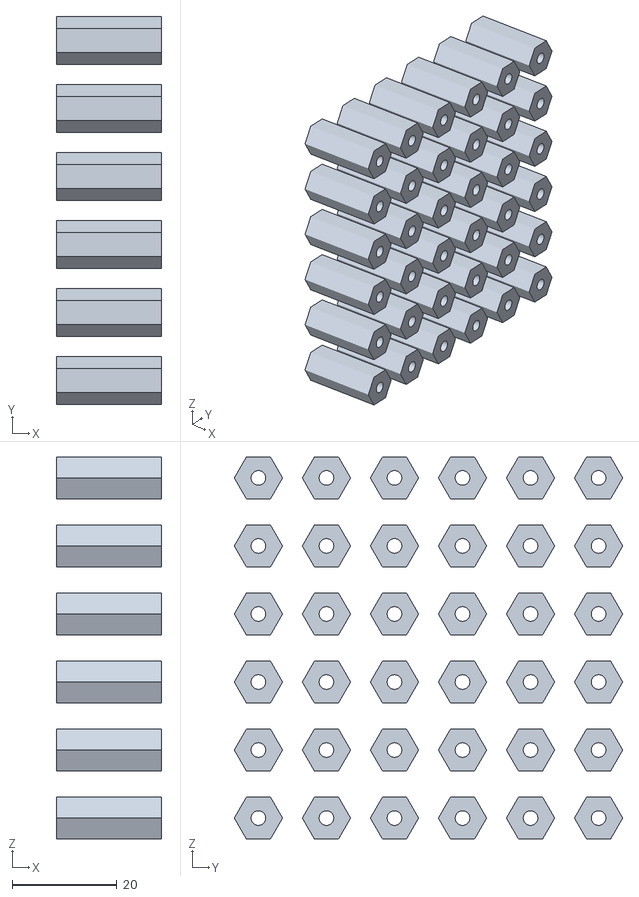
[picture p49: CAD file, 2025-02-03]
DenizAltiTasarimDosyalari/uzun ara çubuk.STL
20.0 x 74.2 x 73.0

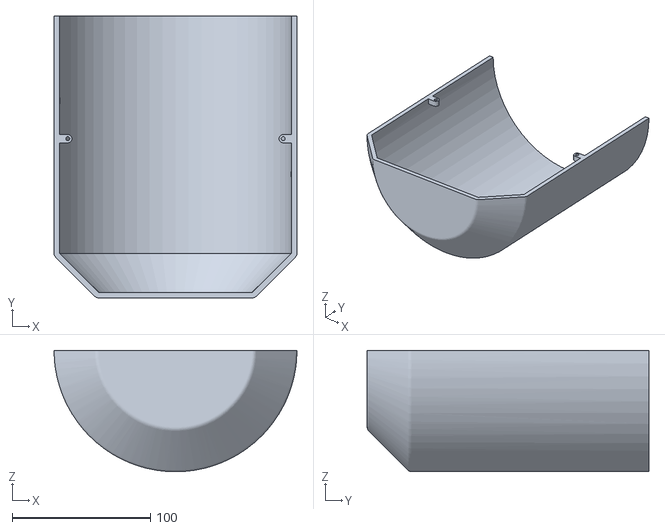
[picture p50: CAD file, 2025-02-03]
DenizAltiTasarimDosyalari/gövde üst kapakk basılacak .STL
176.0 x 204.0 x 88.0

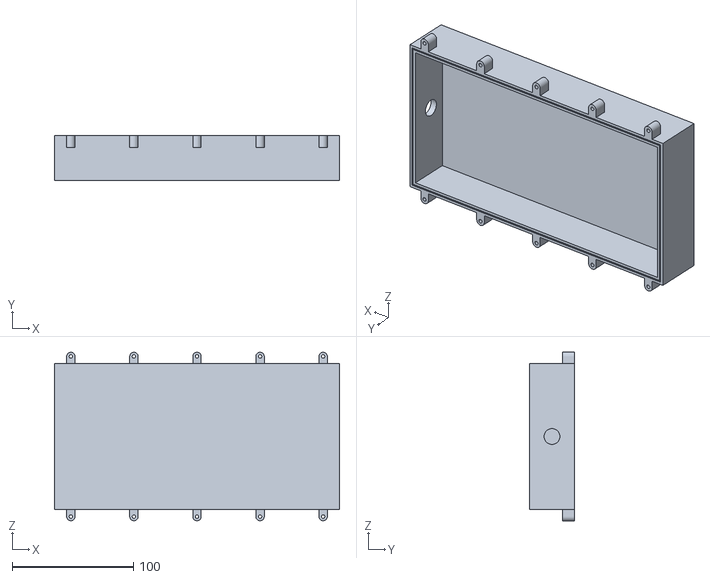
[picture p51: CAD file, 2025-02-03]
DenizAltiTasarimDosyalari/batarya yeni kabı2.1.STL
235.0 x 37.0 x 139.0

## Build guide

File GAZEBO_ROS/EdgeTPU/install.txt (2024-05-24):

pip install -r requirements.txt
python3 -m pip install --extra-index-url https://google-coral.github.io/py-repo/ pycoral
pip3 install --extra-index-url https://google-coral.github.io/py-repo/ pycoral
pip3 install --extra-index-url https://google-coral.github.io/py-repo/ tflite_runtime

pip install pycocotools

sudo apt-get update
sudo apt-get install libgtk2.0-dev pkg-config
pip install opencv-python
pip install -r requirements.txt

curl https://packages.cloud.google.com/apt/doc/apt-key.gpg | sudo apt-key add -

echo "deb https://packages.cloud.google.com/apt coral-edgetpu-stable main" | sudo tee /etc/apt/sources.list.d/coral-edgetpu.list

sudo apt-get update

sudo apt-get install edgetpu-compiler

Edge TPU Derleyicisini Yükleme:

Edge TPU derleyicisini henüz yüklemediyseniz, aşağıdaki komutu kullanarak kurabilirsiniz:

sudo apt-get update
sudo apt-get install edgetpu-compiler

Use code with caution.Bash

Modeli Derleme:

Edge TPU derleyicisini kullanarak modelinizi derlemek için aşağıdaki komutu kullanın:

edgetpu_compiler efficientdet-lite-salad.tflite \
    -o . \
    -a {arch} \
    -s

Use code with caution.Bash

    efficientdet-lite-salad.tflite: Modelinizin dosya adı.

    -o .: Çıktı dosyasının kaydedileceği dizin (mevcut dizin).

    -a {arch}: Edge TPU mimarisi. Örneğin, Coral USB Accelerator için -a v2 veya Coral Dev Board için -a v1 kullanabilirsiniz.

    -s: Tek bir Edge TPU için derleme yapılacağını belirtir.

Çıktı Dosyası:

Derleme işlemi tamamlandıktan sonra, modelinizin Edge TPU'da çalıştırılabilen versiyonu efficientdet-lite-salad_edgetpu.tflite adıyla kaydedilecektir.

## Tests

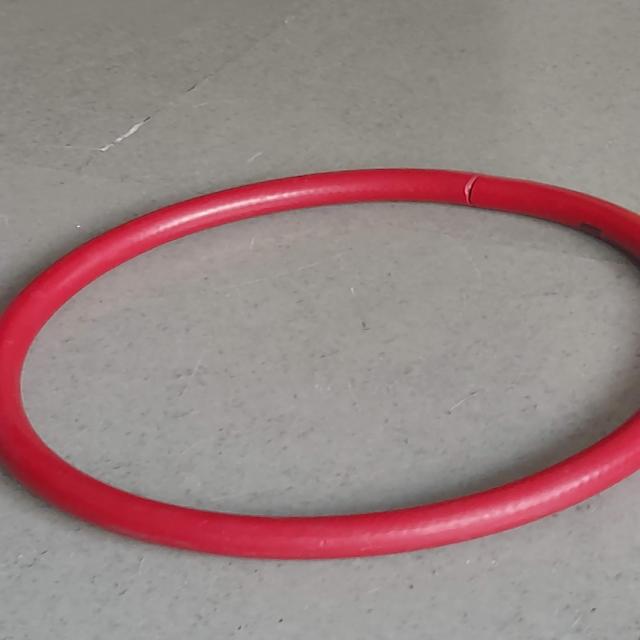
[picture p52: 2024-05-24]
GAZEBO_ROS/EdgeTPU/test/20221114_165807_jpg.rf.f79f3425ad838b5da8cdd3fa02d7a686.jpg

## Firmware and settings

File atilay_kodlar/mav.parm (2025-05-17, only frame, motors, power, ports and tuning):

ATC_ANGLE_BOOST  1
ATC_ANG_LIM_TC   1.000000
ATC_ANG_PIT_P    6.000000
ATC_ANG_RLL_P    6.000000
ATC_ANG_YAW_P    6.000000
ATC_RATE_FF_ENAB 1
ATC_RATE_P_MAX   0.000000
ATC_RATE_R_MAX   0.000000
ATC_RATE_Y_MAX   180.000000
ATC_RAT_PIT_D    0.003600
ATC_RAT_PIT_FF   0.000000
ATC_RAT_PIT_FLTD 30.000000
ATC_RAT_PIT_FLTE 0.000000
ATC_RAT_PIT_FLTT 30.000000
ATC_RAT_PIT_I    0.090000
ATC_RAT_PIT_IMAX 0.444000
ATC_RAT_PIT_P    0.135000
ATC_RAT_PIT_SMAX 0.000000
ATC_RAT_RLL_D    0.003600
ATC_RAT_RLL_FF   0.000000
ATC_RAT_RLL_FLTD 30.000000
ATC_RAT_RLL_FLTE 0.000000
ATC_RAT_RLL_FLTT 30.000000
ATC_RAT_RLL_I    0.090000
ATC_RAT_RLL_IMAX 0.444000
ATC_RAT_RLL_P    0.135000
ATC_RAT_RLL_SMAX 0.000000
ATC_RAT_YAW_D    0.000000
ATC_RAT_YAW_FF   0.000000
ATC_RAT_YAW_FLTD 5.000000
ATC_RAT_YAW_FLTE 0.000000
ATC_RAT_YAW_FLTT 5.000000
ATC_RAT_YAW_I    0.018000
ATC_RAT_YAW_IMAX 0.222000
ATC_RAT_YAW_P    0.180000
ATC_RAT_YAW_SMAX 0.000000
BATT2_MONITOR    0
BATT3_MONITOR    0
BATT4_MONITOR    0
BATT5_MONITOR    0
BATT6_MONITOR    0
BATT7_MONITOR    0
BATT8_MONITOR    0
BATT9_MONITOR    0
BATT_MONITOR     0
FRAME_CONFIG     1
INS_GYRO_FILTER  20
INS_HNTCH_ENABLE 0
MOT_10_DIRECTION 1
MOT_11_DIRECTION 1
MOT_12_DIRECTION 1
MOT_1_DIRECTION  -1
MOT_2_DIRECTION  -1
MOT_3_DIRECTION  -1
MOT_4_DIRECTION  -1
MOT_5_DIRECTION  -1
MOT_6_DIRECTION  -1
MOT_7_DIRECTION  1
MOT_8_DIRECTION  1
MOT_9_DIRECTION  1
MOT_BAT_CURR_MAX 0.000000
MOT_BAT_CURR_TC  5.000000
MOT_BAT_IDX      0
MOT_BAT_VOLT_MAX 0.000000
MOT_BAT_VOLT_MIN 0.000000
MOT_BOOST_SCALE  0.000000
MOT_FV_CPLNG_K   1.000000
MOT_HOVER_LEARN  2
MOT_PWM_MAX      2000
MOT_PWM_MIN      1000
MOT_PWM_TYPE     0
MOT_SAFE_DISARM  0
MOT_SAFE_TIME    1.000000
MOT_SLEW_DN_TIME 0.000000
MOT_SLEW_UP_TIME 0.000000
MOT_SPIN_ARM     0.100000
MOT_SPIN_MAX     0.950000
MOT_SPIN_MIN     0.150000
MOT_SPOOL_TIME   0.500000
MOT_THST_EXPO    0.650000
MOT_THST_HOVER   0.500000
MOT_YAW_HEADROOM 200
SERIAL0_BAUD     115
SERIAL0_PROTOCOL 2
SERIAL1_BAUD     57
SERIAL1_OPTIONS  0
SERIAL1_PROTOCOL 2
SERIAL2_BAUD     57
SERIAL2_OPTIONS  0
SERIAL2_PROTOCOL 2
SERIAL3_BAUD     38
SERIAL3_OPTIONS  0
SERIAL3_PROTOCOL 5
SERIAL4_BAUD     38
SERIAL4_OPTIONS  0
SERIAL4_PROTOCOL 5
SERIAL5_BAUD     57
SERIAL5_OPTIONS  0
SERIAL5_PROTOCOL -1
SERVO1_FUNCTION  33
SERVO1_MAX       1900
SERVO1_MIN       1100
SERVO1_REVERSED  0
SERVO1_TRIM      1495
SERVO2_FUNCTION  34
SERVO2_MAX       1900
SERVO2_MIN       1100
SERVO2_REVERSED  0
SERVO2_TRIM      1495
SERVO3_FUNCTION  35
SERVO3_MAX       1900
SERVO3_MIN       1100
SERVO3_REVERSED  0
SERVO3_TRIM      1495
SERVO4_FUNCTION  36
SERVO4_MAX       1900
SERVO4_MIN       1100
SERVO4_REVERSED  0
SERVO4_TRIM      1495
SERVO5_FUNCTION  37
SERVO5_MAX       1900
SERVO5_MIN       1100
SERVO5_REVERSED  0
SERVO5_TRIM      1495
SERVO6_FUNCTION  38
SERVO6_MAX       1900
SERVO6_MIN       1100
SERVO6_REVERSED  0
SERVO6_TRIM      1495
SERVO7_FUNCTION  0
SERVO7_MAX       1900
SERVO7_MIN       1100
SERVO7_REVERSED  0
SERVO7_TRIM      1495
SERVO8_FUNCTION  0
SERVO8_MAX       1900
SERVO8_MIN       1100
SERVO8_REVERSED  0
SERVO8_TRIM      1495
SERVO9_FUNCTION  59
SERVO9_MAX       1900
SERVO9_MIN       1100
SERVO9_REVERSED  0
SERVO9_TRIM      1500

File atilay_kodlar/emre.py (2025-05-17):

import math
import RPi.GPIO as IO
import threading
from time import sleep, localtime
# from tqdm import tqdm
import time
# IO.setwarnings(False)
IO.setmode(IO.BCM)

HexDigits = [0x3f, 0x06, 0x5b, 0x4f, 0x66, 0x6d, 0x7d,
             0x07, 0x7f, 0x6f, 0x77, 0x7c, 0x39, 0x5e, 0x79, 0x71]

ADDR_AUTO = 0x40
ADDR_FIXED = 0x44
STARTADDR = 0xC0
# DEBUG = False


class TM1637:
    __doublePoint = False
    __Clkpin = 0
    __Datapin = 0
    __brightness = 1.0  # default to max brightness
    __currentData = [0, 0, 0, 0]

    def __init__(self, CLK, DIO, brightness):
        self.__Clkpin = CLK
        self.__Datapin = DIO
        self.__brightness = brightness
        IO.setup(self.__Clkpin, IO.OUT)
        IO.setup(self.__Datapin, IO.OUT)

    def cleanup(self):
        """Stop updating clock, turn off display, and cleanup GPIO"""
        self.StopClock()
        self.Clear()
        IO.cleanup()

    def Clear(self):
        b = self.__brightness
        point = self.__doublePoint
        self.__brightness = 0
        self.__doublePoint = False
        data = [0x7F, 0x7F, 0x7F, 0x7F]
        self.Show(data)
        # Restore previous settings:
        self.__brightness = b
        self.__doublePoint = point

    def ShowInt(self, i):
        s = str(i)
        self.Clear()
        for i in range(0, len(s)):
            self.Show1(i, int(s[i]))

    def Show(self, data):
        for i in range(0, 4):
            self.__currentData[i] = data[i]

        self.start()
        self.writeByte(ADDR_AUTO)
        self.br()
        self.writeByte(STARTADDR)
        for i in range(0, 4):
            self.writeByte(self.coding(data[i]))
        self.br()
        self.writeByte(0x88 + int(self.__brightness))
        self.stop()

    def Show1(self, DigitNumber, data):
        """show one Digit (number 0...3)"""
        if(DigitNumber < 0 or DigitNumber > 3):
            return  # error

        self.__currentData[DigitNumber] = data

        self.start()
        self.writeByte(ADDR_FIXED)
        self.br()
        self.writeByte(STARTADDR | DigitNumber)
        self.writeByte(self.coding(data))
        self.br()
        self.writeByte(0x88 + int(self.__brightness))
        self.stop()

    def SetBrightness(self, percent):
        """Accepts percent brightness from 0 - 1"""
        max_brightness = 7.0
        brightness = math.ceil(max_brightness * percent)
        if (brightness < 0):
            brightness = 0
        if(self.__brightness != brightness):
            self.__brightness = brightness
            self.Show(self.__currentData)

    def ShowDoublepoint(self, on):
        """Show or hide double point divider"""
        if(self.__doublePoint != on):
            self.__doublePoint = on
            self.Show(self.__currentData)

    def writeByte(self, data):
        for i in range(0, 8):
            IO.output(self.__Clkpin, IO.LOW)
            if(data & 0x01):
                IO.output(self.__Datapin, IO.HIGH)
            else:
                IO.output(self.__Datapin, IO.LOW)
            data = data >> 1
            IO.output(self.__Clkpin, IO.HIGH)

        # wait for ACK
        IO.output(self.__Clkpin, IO.LOW)
        IO.output(self.__Datapin, IO.HIGH)
        IO.output(self.__Clkpin, IO.HIGH)
        IO.setup(self.__Datapin, IO.IN)

        while(IO.input(self.__Datapin)):
            sleep(0.001)
            if(IO.input(self.__Datapin)):
                IO.setup(self.__Datapin, IO.OUT)
                IO.output(self.__Datapin, IO.LOW)
                IO.setup(self.__Datapin, IO.IN)
        IO.setup(self.__Datapin, IO.OUT)

    def start(self):
        """send start signal to TM1637"""
        IO.output(self.__Clkpin, IO.HIGH)
        IO.output(self.__Datapin, IO.HIGH)
        IO.output(self.__Datapin, IO.LOW)
        IO.output(self.__Clkpin, IO.LOW)

    def stop(self):
        IO.output(self.__Clkpin, IO.LOW)
        IO.output(self.__Datapin, IO.LOW)
        IO.output(self.__Clkpin, IO.HIGH)
        IO.output(self.__Datapin, IO.HIGH)

    def br(self):
        """terse break"""
        self.stop()
        self.start()

    def coding(self, data):
        if(self.__doublePoint):
            pointData = 0x80
        else:
            pointData = 0

        if(data == 0x7F):
            data = 0
        else:
            data = HexDigits[data] + pointData
        return data

    def clock(self, military_time):
        """Clock script modified from:
            https://github.com/johnlr/raspberrypi-tm1637"""
        self.ShowDoublepoint(True)
        while (not self.__stop_event.is_set()):
            t = localtime()
            hour = t.tm_hour
            if not military_time:
                hour = 12 if (t.tm_hour % 12) == 0 else t.tm_hour % 12
            d0 = hour // 10 if hour // 10 else 0
            d1 = hour % 10
            d2 = t.tm_min // 10
            d3 = t.tm_min % 10
            digits = [d0, d1, d2, d3]
            self.Show(digits)
            # # Optional visual feedback of running alarm:
            # print digits
            # for i in tqdm(range(60 - t.tm_sec)):
            for i in range(60 - t.tm_sec):
                if (not self.__stop_event.is_set()):
                    sleep(1)

    def StartClock(self, military_time=True):
        # Stop event based on: http://stackoverflow.com/a/6524542/3219667
        self.__stop_event = threading.Event()
        self.__clock_thread = threading.Thread(
            target=self.clock, args=(military_time,))
        self.__clock_thread.start()

    def StopClock(self):
        try:
            print('Attempting to stop live clock')
            self.__stop_event.set()
        except:
            print('No clock to close')


if __name__ == "__main__":
    """Confirm the display operation"""
    display = TM1637(CLK=21, DIO=20, brightness=1.0)

    display.Clear()
    for i in range(10):
        for j in range(10):
            time.sleep(1)

            digits = [0, 0,i,j]
            display.Show(digits)
    """
    print("1234  - Working? (Press Key)")
    scrap =input()

    print("Updating one digit at a time:")
    display.Clear()
    display.Show1(1, 3)
    sleep(0.5)
    display.Show1(2, 2)
    sleep(0.5)
    display.Show1(3, 1)
    sleep(0.5)
    display.Show1(0, 4)
    print("4321  - (Press Key)")
    scrap = input()
    """
    print("Add double point\n")
    display.ShowDoublepoint(True)
    sleep(0.2)
    print("Brightness Off")
    display.SetBrightness(0)
    sleep(0.5)
    print("Full Brightness")
    display.SetBrightness(1)
    sleep(0.5)
    print("30% Brightness")
    display.SetBrightness(0.3)
    sleep(0.3)

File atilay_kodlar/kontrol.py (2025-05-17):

from atilay import atilay
import time
from gpiozero import LED
from time import sleep

led1=LED(18)
led2=LED(27)




master=atilay.set(0)
#atilay.arm(master)
pwm=1500
a=0

#time.sleep(2)

def uzaklik():
	
	y=atilay.piksel("y")
	derinlik=atilay.lidar("z")
	try:
		y=int(y)
		derinlik=int(derinlik)
	except:
		y=None
		derinlik=None

	if y != None and derinlik != None and y != 0:
		distance=abs(240*(derinlik-2)/y)
		return distance
	else:
		return None
	

def dip_status():
	dosya=open("dip_status","r")
	s=dosya.read()
	dosya.close()
	if s=="True":
		return True
	else:
		return False
def dip_cam_activate(a=True):
	if a:
		dosya=open("dip_status","w")
		dosya.write("True")
		dosya.close()

	else:
		dosya=open("dip_status","w")
		dosya.write("False")
		dosya.close()

def red_status ():
    
        dosya = open("/home/rasp/atilay/red_status", "r")
        gorev = dosya.read()
        dosya.close()

        if gorev=="True":
            return True
        else:
            return False


def rota_duzelt(ilk_derece,master,gorev=False,default=20):
	son_derece=atilay.pusula(master)
	fark=son_derece-ilk_derece
	atilay.sifirla()
	if abs(fark)>=default:

		while True:
			gorev=red_status()
			son_derece=atilay.pusula(master)
			fark=son_derece-ilk_derece
			if gorev:
				x,y=ortala(master)
				atilay.sifirla()
				return gorev

			if fark>5:
				atilay.sag_sol(1470)
			elif fark<-5:
				atilay.sag_sol(1532)

			else:
				atilay.sifirla()
				return False




def don(master,tekrar=8,gorev=False):
	kontrol=0

	ilk_derece=atilay.pusula(master)
	print("dondeyim..")
	atilay.sifirla()
	while True:
		atilay.sag_sol(1530,master)

		son_derece=atilay.pusula(master)
		son_fark=abs(son_derece-ilk_derece)
		gorev=red_status()

		if abs(son_fark>=45) or gorev:
			ilk_derece=atilay.pusula(master)
			kontrol+=1
			if kontrol>=tekrar or gorev:
				atilay.sifirla()
				return gorev





atilay.servo(7,1300,master)
def ortala(master,dip_cam=False):
	tekrar=0
	while tekrar <= 500:
		tekrar+=1

		try:
			x=int(atilay.piksel("x"))
			y=int(atilay.piksel("y"))
		except:
			print("int error...")
			

		if x>5:
			atilay.yanla(1540,master)
			#atilay.sifirla()
		elif x<-5:
			atilay.yanla(1480,master)
			#atilay.sifirla

		if dip_cam:
			if y>5:
				atilay.ileri_geri(1540,master)
				#atilay.sifirla()
			elif y<-5:
				atilay.ileri_geri(1440,master)
				#atilay.sifirla()

	atilay.sifirla()
	return x,y


def ileri(master,gorev=red_status()):
	print("ileri fonksiyonuna geldim")
	if gorev:
		return True

	ilk_derece=atilay.pusula(master)

	while True:
		for i in range(100):
			atilay.ileri_geri(1540,master)
			gorev=rota_duzelt(ilk_derece,master,gorev)
			if gorev:
				return gorev
		gorev=don(master,2)
		if gorev:
			atilay.sifirla()
			return gorev







atilay.sifirla()
#atilay.arm(master)
pwm=1470
ekle=1
# sag_sol = 1499 - 1512  orta: 1505
# ileri_geri = 1487 - 1491 orta: 1489
# bat_cik = 1507 - 1515 orta: 1511
# yanla = 1500 - 1503 orta: 1501 


def dip_ortala(master,gorev):

        while True:
                ledon()
                x,y=ortala(master)
                gorev=red_status()
                if not gorev:
                        atilay.sifirla()
                        #ledoff(led1,led2)
                        break
                if x <20 and x>-20 and y<20 and y>-20:
                        atilay.sifirla()
                        sayac=0
                        while True:
                                time.sleep(0.1)
                                sayac+=1
                                gorev=red_status()
                                if not gorev:
                                        break
                                #ledon(led1,led2)
                                time.sleep(0.5)
                                atilay.bat_cik(1400,master)
                                if sayac>=300:
                                        break

atilay.derinlik(20)
atilay.servo(7,2200,master)

dip_cam_activate(False)
time.sleep(2)
atilay.arm(master)
while True:
        led2.on()
        print("ana döngüdeyim..")
        gorev=don(master,6)

        if not gorev:
                led2.off()
                gorev=ileri(master)
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

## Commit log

2024-06-25 oto commit 2024-06-25 18:44:01.825879
    [veriler.csv]
2024-06-29 oto commit 2024-06-29 16:52:01.770667
    [veriler.csv]
2024-06-29 oto commit 2024-06-29 16:54:01.881127
    [veriler.csv]
2024-06-29 oto commit 2024-06-29 16:56:01.681575
    [veriler.csv]
2024-06-29 oto commit 2024-06-29 16:59:01.782494
    [veriler.csv]
2024-06-29 oto commit 2024-06-29 17:01:01.727344
    [veriler.csv]
2024-06-29 oto commit 2024-06-29 17:07:01.633598
    [veriler.csv]
2024-06-29 oto commit 2024-06-29 17:10:01.431793
    [veriler.csv]
2024-06-29 oto commit 2024-06-29 17:17:02.021769
    [veriler.csv]
2024-06-29 oto commit 2024-06-29 17:18:01.813217
    [veriler.csv]
2024-06-29 oto commit 2024-06-29 17:20:01.276406
    [veriler.csv]
2024-06-29 oto commit 2024-06-29 17:21:01.200087
    [veriler.csv]
2024-06-29 oto commit 2024-06-29 17:23:01.334323
    [veriler.csv]
2025-02-03 STL and gcode Pushing
    [ara çubuklar 2.STL, batarya yeni kabı2.1.1.STL, batarya yeni kabı2.1.STL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]
2025-05-17 kodlar ve kütüphane
    [mav.parm, veriler.csv]
